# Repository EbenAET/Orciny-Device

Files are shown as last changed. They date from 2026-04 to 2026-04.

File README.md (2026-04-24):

# Orciny Device Unified Firmware (V 1.0.0) ~ Show Release

## Overview

This repository contains the complete, unified firmware and documentation for the Orciny Device: a single-controller, multi-effect system built around the Adafruit Feather RP2040. All device logic, state management, and effect sequencing are implemented in a single, modular program with robust configuration and documentation.

## Backstage Instructions

- **Setup:**
	- Check that 5V battery is plugged in to device USB cable
		- Located in broken end of device
		- Be sure 5V charging cable is unplugged and detatched from device
	- Tuck Programming/Charging cable into center and secure end
		- Located between "Core" and "Rotary" setions
		- Gently feed excess cable into cavity until only painted portion remains
		- Stick velcro end of cable to receiving pad
	- Test Device
		- Press "power" button to enable outputs
			- Back end should start slowly sparking
		- Press "play/pause" button to start sequence
			- Core animation should start (slowly at first, then ramping up)
		- If full program runs, its ready to go! Set for show!
	- Handoff
		- When in standby to hand off, check that device is still in "inactive/idle" by pressing "power" button
		- If in the correct state, there should be intermittent sparks and no other animations
		- If other animations start up, let the program run through or press the "Break" button to fastforward to the device failure sequence, after which the device will return to "Idle" sequence with outputs off
			- At this point, press the "power" button to make sure outputs are on and device is in "Inactive/Idle"
- **Charging:**
	- Device has two batteries for operation
		- 5V power bank in tail
		- 3.7V LiPO internally
	- 5V battery should only need charging every couple of performances if device USB is unplugged when not in use
		- Charges with MicroUSB cable as needed
	- 3.7V battery should be charged before each performance since we can't easily check status and we can't easily disconnect it
		- Charges with programming/charging cable tucked into midsection of device
		
### Physical Controls

- SW1 (`GP27`): Toggle outputs on/off
- SW2 (`GP28`): Play/Pause
- SW3 (`GP29`): Jump to Failure
- Hold SW1 + SW3 for 5 seconds: Reset to State 1 with outputs off

## Troubleshooting

- **Check troubleshooting document**
- **Additional assistance**
	- Contact Emery Smith or Eben Alguire
	
## Architecture

- **Main Program:**
	- `arduino/Orciny_Device/Orciny_Device.ino` — The only sketch you need. Implements the full state machine, effect sequencing, physical controls, and safety logic.
- **Configuration:**
	- `arduino/Orciny_Device/DeviceConfig.h` — All pin assignments and tunable parameters in one place.
- **Animation & Palette Data:**
	- `arduino/Orciny_Device/ColorPalettes.h`, `arduino/Orciny_Device/AnimationPalettes.h` — All color, timing, and animation data.
- **Shared Logic:**
	- `arduino/libraries/OrcinyCommon` — Protocols, data structures, and shared code.
- **Optional Advanced Scenes:**
	- `arduino/libraries/OrcinyEffects` — Pre-built effect scenes for advanced/hybrid workflows (not required for standard operation).
- **Documentation:**
	- Markdown files in `arduino/Orciny_Device/` detail the animation timeline, troubleshooting, and visualizations.

## Project Structure

- `arduino/Orciny_Device/Orciny_Device.ino` — Main program
- `arduino/Orciny_Device/DeviceConfig.h` — Pin/parameter config
- `arduino/Orciny_Device/Orciny_Device_Animation_Timeline.md` — Detailed animation timeline
- `arduino/Orciny_Device/Orciny_Device_Animation_Timeline_Visual.md` — Visual timeline (ASCII/Mermaid)
- `arduino/Orciny_Device/Orciny_Device_Troubleshooting.md` — Troubleshooting guide
- `arduino/libraries/OrcinyCommon` — Shared code
- `arduino/libraries/OrcinyEffects` — Optional advanced scenes
- `arduino/rp2040_fx_starter` — Minimal starter sketch (for bring-up only)
- `arduino/depreciated/` — Legacy/old sketches

## How to Program

1. **Set Up Arduino IDE:**
	 - Set your Sketchbook location to the repo’s `arduino` folder.
	 - Install required libraries: Adafruit NeoPixel, Adafruit PWM Servo Driver Library.
2. **Open the Main Sketch:**
	 - Open `arduino/Orciny_Device/Orciny_Device.ino`.
	 - Select the Feather RP2040 board.
3. **Configure Hardware:**
	 - Edit `DeviceConfig.h` for your pinout and hardware specifics.
4. **Upload and Test:**
	 - Upload to your device and test with the physical switches.
5. **Reference Documentation:**
	 - See the Markdown docs for animation timing, troubleshooting, and wiring.
	 
## Documentation

- [Animation Timeline](arduino/Orciny_Device/Orciny_Device_Animation_Timeline.md): State-by-state effect breakdown
- [Troubleshooting](arduino/Orciny_Device/Orciny_Device_Troubleshooting.md): Physical device troubleshooting

## Versioning & Stability

- **Current Version:** V 0.9.0
- All configuration, palette, and animation headers are centralized.
- State-tracking and reset logic are robust and up-to-date.
- Use this version as your restore point for stable builds.

## Hardware & Wiring Notes

- All pin/parameter definitions: `DeviceConfig.h`
- Color/animation minutiae: `ColorPalettes.h`, `AnimationPalettes.h`
- Power, wiring, and hardware are detailed in the troubleshooting and timeline docs.
- This firmware is a framework: PWM levels, animation timing, and thermal limits require bench validation for new or modified builds.

---

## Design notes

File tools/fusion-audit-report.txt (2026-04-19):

MODE=Audit
MCP_URL=http://127.0.0.1:27182/mcp
REPO_PATH=C:\Users\ebena\OneDrive - University of Illinois - Urbana\Documents\GitHub\Orciny-Device
EXPORT_ROOT=C:\Users\ebena\OneDrive - University of Illinois - Urbana\Documents\GitHub\Orciny-Device\3d Models\Archive\fusion_auto
PROJECT_FILTER=
NAMELIKE_FILTER=
FORMAT_FILTER=f3d,step
PROJECT_MAP_PATH=C:\Users\ebena\OneDrive - University of Illinois - Urbana\Documents\GitHub\Orciny-Device\tools\fusion-project-map.json
PROJECT_MAP_ACTIVE=True
MATCH_COUNT=37
MATCH=0000 Device Assembly | urn:adsk.wipprod:dm.lineage:0i7we0qBRXyN4Au_lZAOfA | City and the City - Orciny Device | City and the City - Orciny Device | subfolder=orciny-device | formats=f3d,step,stl
MATCH=Donuts | urn:adsk.wipprod:dm.lineage:x_f3pI8QSxqb1imuMA4Tkw | City and the City - Orciny Device | City and the City - Orciny Device | subfolder=orciny-device | formats=f3d,step,stl
MATCH=Large disk insert | urn:adsk.wipprod:dm.lineage:e5Ka2zAoSriwOnS_mKsbtw | City and the City - Orciny Device | City and the City - Orciny Device | subfolder=orciny-device | formats=f3d,step,stl
MATCH=Pincer2 | urn:adsk.wipprod:dm.lineage:Z4H9nMHJRkywdjsSsq7myw | City and the City - Orciny Device | City and the City - Orciny Device | subfolder=orciny-device | formats=f3d,step,stl
MATCH=adafruit | urn:adsk.wipprod:dm.lineage:Ej6vKYrnSt-ZIFgxbDMd9g | City and the City - Orciny Device | Circuit | subfolder=orciny-device | formats=f3d,step,stl
MATCH=Pin | urn:adsk.wipprod:dm.lineage:PLMYrBxTQdqTRPHx7Qjl8w | City and the City - Orciny Device | City and the City - Orciny Device | subfolder=orciny-device | formats=f3d,step,stl
MATCH=End connector | urn:adsk.wipprod:dm.lineage:xL0HUBYZQrGGkRIrOdHDPw | City and the City - Orciny Device | City and the City - Orciny Device | subfolder=orciny-device | formats=f3d,step,stl
MATCH=Nozzle | urn:adsk.wipprod:dm.lineage:XH76Vv6oStSqThVJ8LdOsw | City and the City - Orciny Device | City and the City - Orciny Device | subfolder=orciny-device | formats=f3d,step,stl
MATCH=Rotary Shaft | urn:adsk.wipprod:dm.lineage:Y_C4eCmAQlGzDhUTAhTmWw | City and the City - Orciny Device | City and the City - Orciny Device | subfolder=orciny-device | formats=f3d,step,stl
MATCH=Coupler | urn:adsk.wipprod:dm.lineage:pr6ihEBnSuqMdRxkfSCbQw | City and the City - Orciny Device | City and the City - Orciny Device | subfolder=orciny-device | formats=f3d,step,stl
MATCH=Central shaft | urn:adsk.wipprod:dm.lineage:qKA4xiB4RSe2X-p6imrm5g | City and the City - Orciny Device | City and the City - Orciny Device | subfolder=orciny-device | formats=f3d,step,stl
MATCH=Broken tail | urn:adsk.wipprod:dm.lineage:KY0QbmYLRIuuyMJGiDZOdw | City and the City - Orciny Device | City and the City - Orciny Device | subfolder=orciny-device | formats=f3d,step,stl
MATCH=Mounting Martrix | urn:adsk.wipprod:dm.lineage:OBUW4VHMSKGCA77YboDdjg | City and the City - Orciny Device | City and the City - Orciny Device | subfolder=orciny-device | formats=f3d,step,stl
MATCH=emeey pinchers pt1 | urn:adsk.wipprod:dm.lineage:gWEqI1OyTM-vEEHmxptcwQ | City and the City - Orciny Device | Archive | subfolder=orciny-device | formats=f3d,step,stl
MATCH=Pincer Mesh | urn:adsk.wipprod:dm.lineage:DkKWn12oQ7KZ3K4VdfnyJQ | City and the City - Orciny Device | Archive | subfolder=orciny-device | formats=f3d,step,stl
MATCH=Clay pincer meshmodel | urn:adsk.wipprod:dm.lineage:GIoec0_ZQzCYo7EZ0XneOQ | City and the City - Orciny Device | Mesh scans | subfolder=orciny-device | formats=f3d,step,stl
MATCH=Device Nozzle | urn:adsk.wipprod:dm.lineage:wPSjv7ReQXulWAZpgUlfvQ | City and the City - Orciny Device | Archive | subfolder=orciny-device | formats=f3d,step,stl
MATCH=Pincer | urn:adsk.wipprod:dm.lineage:LqhbNozhQHq2CwXfs8nBlQ | City and the City - Orciny Device | Archive | subfolder=orciny-device | formats=f3d,step,stl
MATCH=emery test | urn:adsk.wipprod:dm.lineage:FYrKI2XZQSa07a1-etMyPg | City and the City - Orciny Device | Archive | subfolder=orciny-device | formats=f3d,step,stl
MATCH=Emery Test | urn:adsk.wipprod:dm.lineage:BRCgBeIaSra0wubaWRF43Q | City and the City - Orciny Device | Archive | subfolder=orciny-device | formats=f3d,step,stl
MATCH=emery test | urn:adsk.wipprod:dm.lineage:FaK44H6cSXKmsoEH3gZrqg | City and the City - Orciny Device | Archive | subfolder=orciny-device | formats=f3d,step,stl
MATCH=Nozzle Cap | urn:adsk.wipprod:dm.lineage:_48LmerfRO-RmRAW0qVxWA | City and the City - Orciny Device | Archive | subfolder=orciny-device | formats=f3d,step,stl
MATCH=000 Claw assembly | urn:adsk.wipprod:dm.lineage:s7H_Vr9sT2ukSLe7j24oaw | Orciny device | Orciny device | subfolder=orciny-device-next | formats=f3d,step,stl
MATCH=Screw | urn:adsk.wipprod:dm.lineage:RjQVy1nPQRKoVIJjv0cjCQ | Orciny device | Orciny device | subfolder=orciny-device-next | formats=f3d,step,stl
MATCH=0000 Effect Assembly | urn:adsk.wipprod:dm.lineage:MgjUV8lTTwCATlut9x-gGg | Radium Girls | Radium Girls | subfolder=radium-girls | formats=f3d,step
MATCH=Bung | urn:adsk.wipprod:dm.lineage:AIxvFMD1TlaubFQTPOqOWw | Radium Girls | Radium Girls | subfolder=radium-girls | formats=f3d,step
MATCH=PCB3 | urn:adsk.wipprod:dm.lineage:rGX81_E_SMe7DuCYjnw8zg | Radium Girls | Radium Girls | subfolder=radium-girls | formats=f3d,step
MATCH=PCB3 | urn:adsk.wipprod:dm.lineage:CceROSsmQnKhIDO-hsE-gQ | Radium Girls | Radium Girls | subfolder=radium-girls | formats=f3d,step
MATCH=PCB3 | urn:adsk.wipprod:dm.lineage:Wt0j8bskTZ-lOoiLNmkJyQ | Radium Girls | Radium Girls | subfolder=radium-girls | formats=f3d,step
MATCH=PCB Assembly | urn:adsk.wipprod:dm.lineage:iWvl_ixJS6KupJv7bIMY4w | Radium Girls | Radium Girls | subfolder=radium-girls | formats=f3d,step
MATCH=PCB3 | urn:adsk.wipprod:dm.lineage:zwZO-YlHRzK7X6FbYi3zog | Radium Girls | Radium Girls | subfolder=radium-girls | formats=f3d,step
MATCH=4 pin fpc | urn:adsk.wipprod:dm.lineage:DiI6vidnQ76GTtji4kISsQ | Radium Girls | Radium Girls | subfolder=radium-girls | formats=f3d,step
MATCH=2026-02-20_17-37-38_Library | urn:adsk.wipprod:dm.lineage:nSYjRbDsSKOJwaZLO-sgmA | Radium Girls | Radium Girls | subfolder=radium-girls | formats=f3d,step
MATCH=CONN4_93-0470_MOL | urn:adsk.wipprod:dm.lineage:B5IE1y8fR1q9EawdSpntRA | Radium Girls | Radium Girls | subfolder=radium-girls | formats=f3d,step
MATCH=4pin FPC Connector | urn:adsk.wipprod:dm.lineage:t7W2Dlk1TRiYh1G_xvv78A | Radium Girls | Radium Girls | subfolder=radium-girls | formats=f3d,step
MATCH=Connectorcust | urn:adsk.wipprod:dm.lineage:igUmLseoQQ6BJsJLfTLd6g | Radium Girls | Radium Girls | subfolder=radium-girls | formats=f3d,step
MATCH=PCB2 | urn:adsk.wipprod:dm.lineage:SoFJXjL8RjyrG6MS-hq-GQ | Radium Girls | Radium Girls | subfolder=radium-girls | formats=f3d,step

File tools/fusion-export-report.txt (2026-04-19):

MODE=Export
MCP_URL=http://127.0.0.1:27182/mcp
REPO_PATH=C:\Users\ebena\OneDrive - University of Illinois - Urbana\Documents\GitHub\Orciny-Device
EXPORT_ROOT=C:\Users\ebena\OneDrive - University of Illinois - Urbana\Documents\GitHub\Orciny-Device\3d Models\Archive\fusion_auto
PROJECT_FILTER=
NAMELIKE_FILTER=
FORMAT_FILTER=f3d,step
PROJECT_MAP_PATH=C:\Users\ebena\OneDrive - University of Illinois - Urbana\Documents\GitHub\Orciny-Device\tools\fusion-project-map.json
PROJECT_MAP_ACTIVE=True
MATCH_COUNT=37
MATCH=0000 Device Assembly | urn:adsk.wipprod:dm.lineage:0i7we0qBRXyN4Au_lZAOfA | City and the City - Orciny Device | City and the City - Orciny Device | subfolder=orciny-device | formats=f3d,step,stl
MATCH=Donuts | urn:adsk.wipprod:dm.lineage:x_f3pI8QSxqb1imuMA4Tkw | City and the City - Orciny Device | City and the City - Orciny Device | subfolder=orciny-device | formats=f3d,step,stl
MATCH=Large disk insert | urn:adsk.wipprod:dm.lineage:e5Ka2zAoSriwOnS_mKsbtw | City and the City - Orciny Device | City and the City - Orciny Device | subfolder=orciny-device | formats=f3d,step,stl
MATCH=Pincer2 | urn:adsk.wipprod:dm.lineage:Z4H9nMHJRkywdjsSsq7myw | City and the City - Orciny Device | City and the City - Orciny Device | subfolder=orciny-device | formats=f3d,step,stl
MATCH=adafruit | urn:adsk.wipprod:dm.lineage:Ej6vKYrnSt-ZIFgxbDMd9g | City and the City - Orciny Device | Circuit | subfolder=orciny-device | formats=f3d,step,stl
MATCH=Pin | urn:adsk.wipprod:dm.lineage:PLMYrBxTQdqTRPHx7Qjl8w | City and the City - Orciny Device | City and the City - Orciny Device | subfolder=orciny-device | formats=f3d,step,stl
MATCH=End connector | urn:adsk.wipprod:dm.lineage:xL0HUBYZQrGGkRIrOdHDPw | City and the City - Orciny Device | City and the City - Orciny Device | subfolder=orciny-device | formats=f3d,step,stl
MATCH=Nozzle | urn:adsk.wipprod:dm.lineage:XH76Vv6oStSqThVJ8LdOsw | City and the City - Orciny Device | City and the City - Orciny Device | subfolder=orciny-device | formats=f3d,step,stl
MATCH=Rotary Shaft | urn:adsk.wipprod:dm.lineage:Y_C4eCmAQlGzDhUTAhTmWw | City and the City - Orciny Device | City and the City - Orciny Device | subfolder=orciny-device | formats=f3d,step,stl
MATCH=Coupler | urn:adsk.wipprod:dm.lineage:pr6ihEBnSuqMdRxkfSCbQw | City and the City - Orciny Device | City and the City - Orciny Device | subfolder=orciny-device | formats=f3d,step,stl
MATCH=Central shaft | urn:adsk.wipprod:dm.lineage:qKA4xiB4RSe2X-p6imrm5g | City and the City - Orciny Device | City and the City - Orciny Device | subfolder=orciny-device | formats=f3d,step,stl
MATCH=Broken tail | urn:adsk.wipprod:dm.lineage:KY0QbmYLRIuuyMJGiDZOdw | City and the City - Orciny Device | City and the City - Orciny Device | subfolder=orciny-device | formats=f3d,step,stl
MATCH=Mounting Martrix | urn:adsk.wipprod:dm.lineage:OBUW4VHMSKGCA77YboDdjg | City and the City - Orciny Device | City and the City - Orciny Device | subfolder=orciny-device | formats=f3d,step,stl
MATCH=emeey pinchers pt1 | urn:adsk.wipprod:dm.lineage:gWEqI1OyTM-vEEHmxptcwQ | City and the City - Orciny Device | Archive | subfolder=orciny-device | formats=f3d,step,stl
MATCH=Pincer Mesh | urn:adsk.wipprod:dm.lineage:DkKWn12oQ7KZ3K4VdfnyJQ | City and the City - Orciny Device | Archive | subfolder=orciny-device | formats=f3d,step,stl
MATCH=Clay pincer meshmodel | urn:adsk.wipprod:dm.lineage:GIoec0_ZQzCYo7EZ0XneOQ | City and the City - Orciny Device | Mesh scans | subfolder=orciny-device | formats=f3d,step,stl
MATCH=Device Nozzle | urn:adsk.wipprod:dm.lineage:wPSjv7ReQXulWAZpgUlfvQ | City and the City - Orciny Device | Archive | subfolder=orciny-device | formats=f3d,step,stl
MATCH=Pincer | urn:adsk.wipprod:dm.lineage:LqhbNozhQHq2CwXfs8nBlQ | City and the City - Orciny Device | Archive | subfolder=orciny-device | formats=f3d,step,stl
MATCH=emery test | urn:adsk.wipprod:dm.lineage:FYrKI2XZQSa07a1-etMyPg | City and the City - Orciny Device | Archive | subfolder=orciny-device | formats=f3d,step,stl
MATCH=Emery Test | urn:adsk.wipprod:dm.lineage:BRCgBeIaSra0wubaWRF43Q | City and the City - Orciny Device | Archive | subfolder=orciny-device | formats=f3d,step,stl
MATCH=emery test | urn:adsk.wipprod:dm.lineage:FaK44H6cSXKmsoEH3gZrqg | City and the City - Orciny Device | Archive | subfolder=orciny-device | formats=f3d,step,stl
MATCH=Nozzle Cap | urn:adsk.wipprod:dm.lineage:_48LmerfRO-RmRAW0qVxWA | City and the City - Orciny Device | Archive | subfolder=orciny-device | formats=f3d,step,stl
MATCH=000 Claw assembly | urn:adsk.wipprod:dm.lineage:s7H_Vr9sT2ukSLe7j24oaw | Orciny device | Orciny device | subfolder=orciny-device-next | formats=f3d,step,stl
MATCH=Screw | urn:adsk.wipprod:dm.lineage:RjQVy1nPQRKoVIJjv0cjCQ | Orciny device | Orciny device | subfolder=orciny-device-next | formats=f3d,step,stl
MATCH=0000 Effect Assembly | urn:adsk.wipprod:dm.lineage:MgjUV8lTTwCATlut9x-gGg | Radium Girls | Radium Girls | subfolder=radium-girls | formats=f3d,step
MATCH=Bung | urn:adsk.wipprod:dm.lineage:AIxvFMD1TlaubFQTPOqOWw | Radium Girls | Radium Girls | subfolder=radium-girls | formats=f3d,step
MATCH=PCB3 | urn:adsk.wipprod:dm.lineage:rGX81_E_SMe7DuCYjnw8zg | Radium Girls | Radium Girls | subfolder=radium-girls | formats=f3d,step
MATCH=PCB3 | urn:adsk.wipprod:dm.lineage:CceROSsmQnKhIDO-hsE-gQ | Radium Girls | Radium Girls | subfolder=radium-girls | formats=f3d,step
MATCH=PCB3 | urn:adsk.wipprod:dm.lineage:Wt0j8bskTZ-lOoiLNmkJyQ | Radium Girls | Radium Girls | subfolder=radium-girls | formats=f3d,step
MATCH=PCB Assembly | urn:adsk.wipprod:dm.lineage:iWvl_ixJS6KupJv7bIMY4w | Radium Girls | Radium Girls | subfolder=radium-girls | formats=f3d,step
MATCH=PCB3 | urn:adsk.wipprod:dm.lineage:zwZO-YlHRzK7X6FbYi3zog | Radium Girls | Radium Girls | subfolder=radium-girls | formats=f3d,step
MATCH=4 pin fpc | urn:adsk.wipprod:dm.lineage:DiI6vidnQ76GTtji4kISsQ | Radium Girls | Radium Girls | subfolder=radium-girls | formats=f3d,step
MATCH=2026-02-20_17-37-38_Library | urn:adsk.wipprod:dm.lineage:nSYjRbDsSKOJwaZLO-sgmA | Radium Girls | Radium Girls | subfolder=radium-girls | formats=f3d,step
MATCH=CONN4_93-0470_MOL | urn:adsk.wipprod:dm.lineage:B5IE1y8fR1q9EawdSpntRA | Radium Girls | Radium Girls | subfolder=radium-girls | formats=f3d,step
MATCH=4pin FPC Connector | urn:adsk.wipprod:dm.lineage:t7W2Dlk1TRiYh1G_xvv78A | Radium Girls | Radium Girls | subfolder=radium-girls | formats=f3d,step
MATCH=Connectorcust | urn:adsk.wipprod:dm.lineage:igUmLseoQQ6BJsJLfTLd6g | Radium Girls | Radium Girls | subfolder=radium-girls | formats=f3d,step
MATCH=PCB2 | urn:adsk.wipprod:dm.lineage:SoFJXjL8RjyrG6MS-hq-GQ | Radium Girls | Radium Girls | subfolder=radium-girls | formats=f3d,step
EXPORTED_COUNT=37
FAILED_COUNT=0
EXPORTED=0000 Device Assembly -> orciny-device
EXPORTED=Donuts -> orciny-device
EXPORTED=Large disk insert -> orciny-device
EXPORTED=Pincer2 -> orciny-device
EXPORTED=adafruit -> orciny-device
EXPORTED=Pin -> orciny-device
EXPORTED=End connector -> orciny-device
EXPORTED=Nozzle -> orciny-device
EXPORTED=Rotary Shaft -> orciny-device
EXPORTED=Coupler -> orciny-device
EXPORTED=Central shaft -> orciny-device
EXPORTED=Broken tail -> orciny-device
EXPORTED=Mounting Martrix -> orciny-device
EXPORTED=emeey pinchers pt1 -> orciny-device
EXPORTED=Pincer Mesh -> orciny-device
EXPORTED=Clay pincer meshmodel -> orciny-device
EXPORTED=Device Nozzle -> orciny-device
EXPORTED=Pincer -> orciny-device
EXPORTED=emery test -> orciny-device
EXPORTED=Emery Test -> orciny-device
EXPORTED=emery test -> orciny-device
EXPORTED=Nozzle Cap -> orciny-device
EXPORTED=000 Claw assembly -> orciny-device-next
EXPORTED=Screw -> orciny-device-next
EXPORTED=0000 Effect Assembly -> radium-girls
EXPORTED=Bung -> radium-girls
EXPORTED=PCB3 -> radium-girls
EXPORTED=PCB3 -> radium-girls
EXPORTED=PCB3 -> radium-girls
EXPORTED=PCB Assembly -> radium-girls
EXPORTED=PCB3 -> radium-girls
EXPORTED=4 pin fpc -> radium-girls
EXPORTED=2026-02-20_17-37-38_Library -> radium-girls
EXPORTED=CONN4_93-0470_MOL -> radium-girls
EXPORTED=4pin FPC Connector -> radium-girls
EXPORTED=Connectorcust -> radium-girls
EXPORTED=PCB2 -> radium-girls

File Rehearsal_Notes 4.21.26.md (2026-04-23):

<!-- Device Rehearsal Notes | V 1.0.0 (Show Release) | Updated: 2026-04-21 -->

# Device Rehearsal Notes

## General Information
- **Date:**
    - April 21, 2026
- **Device/Module:**
    - Orciny Device Production version
- **Tested by:**
    - Eben Alguire, Emery Smith, Chris Ramshaw *Bowden*
- **Purpose/Focus:**
    - Dress Rehearsal 1, Tech

---

## Hardware Notes
- **Observed Issues:**
	- Hard to tell what state its in during early boot mode, but that might be okay
    - Buttons too sensative
    - Pulse filament seems to be linked directly to pump, no fading just on or off when the pump is on or off
        - Work on fix if there is time, but not a priority
- **Physical Adjustments/Repairs:**
	- More rust, more goop
- **Component Status:**
	- Intact, learning

---

## Programming Notes
- **Firmware/Code Version:**
    - 0.7.0
- **Observed Bugs/Glitches:**
	- 
- **Feature Requests/Ideas:**
	-
- **Upload/Debug Actions:**
	-

---

## Miscellaneous
- **Other Observations:**
	- Performer is geting used to the states and button placement
- **Questions/Follow-ups:**
	- Do we need to increase debounce to avoid accidental button presses?
- **To do:**
    - Provide digital and paper copies of the troubleshooting guide, charging and maintenance, etc
    - Package design, instruct backstage and Emery on how to upload, debug, etc
---

*Version: V 1.0.0 (Show Release)*

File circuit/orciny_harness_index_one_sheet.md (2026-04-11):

# Orciny Harness Index (One Sheet)

Quick-reference index for harness identification during build and troubleshooting.

| Label | Harness ID | Primary Connector | From | To | Notes |
|---|---|---|---|---|---|
| 1 | H-PWR-5V | Header / terminal (project-defined) | J801 / +5V input | +5V_BUS branches | 18 AWG trunk, 20 AWG branches |
| 2 | H-BAT-NEO | 2-pin JST | LP503562 #2 + U812 output | +3V7_NEO rail | red=+, black=-; 500-1000 uF bulk cap at strip entry |
| 3 | H-CORE | 3-pin JST HX (NeoPixel side); splits from same 4-pin cable as H-BAT-NEO | RP2040 GP25, +5V_BUS, GND_COMMON | NeoPixel strip DI, +V, GND | Pin 1 red=+V, pin 2 white=signal, pin 3 black+brown=GND; cap across pins 1-3 |
| 4 | H-SW | 4-pin JST | SW1/SW2/SW3, GND | RP2040 A1/A2/A3 (GP27/GP28/GP29), GND | Pin 1 blue=SW1, pin 2 brown=SW2, pin 3 orange=SW3, pin 4 green=GND |
| 5 | H-SPARK | 5-pin DMX cable | RP2040 GP18/GP19/GP20/GP24, GND | Spark channels 1-4 (+ spare) | green=GND; pin 1 red=SP1, pin 2 brown=SP2, pin 3 white=SP3, pin 4 blue=SP4, pin 5 black=spare |
| 6 | H-SERVO | 4-pin JST | ServoWing outputs/power | Servo A/B signal + power branches | Pin 1 white=CH0 sig, pin 2 blue=CH1 sig, pin 3 red=PWR, pin 4 black=GND |
| 7 | H-BEAM-PWR | 4-pin JST (common anode RGB LED) | +5V_BUS, GND_COMMON | Beam load path | Pin 1 white=anode, pin 2 red=R(GP11), pin 3 blue=B(GP13), pin 4 green=G(GP12); GP10 reserved for Prop-Maker PWR enable |
| 8 | H-PELTIER-PWR | Deans Micro2R | +5V_BUS, GND_COMMON | Peltier load path | Pin 1 red=PWR, pin 2 black=GND; GP8->Q9 gate; firmware ON with beam + short cooldown hold |
| 9 | H-PUMP-OPT | Project-defined load/control connector | GPIO unassigned (this revision), +5V_BUS, GND_COMMON | Optional pump driver + load branch | GP8 reassigned to peltier; optional population |
| 10 | H-BAT-RP | Feather battery JST | LP503562 #1 | Feather RP2040 BAT/GND | Direct battery harness; Feather onboard charger path |

## Rail Separation Reminder

- Keep +5V_BUS, RP2040_BAT, and +3V7_NEO isolated from each other.
- Only tie grounds at GND_COMMON.
- Neo battery charger U812 remains dedicated to the Neo rail battery only.

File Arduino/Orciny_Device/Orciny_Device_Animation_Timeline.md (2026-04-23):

# Orciny Device Animation Timeline

**Version:** V 0.9.0  
**Board:** Adafruit Feather RP2040  
**Wings:** Prop-Maker FeatherWing, 8-Channel Servo FeatherWing (PCA9685)

---

## Animation Sequence Timeline
- **Program runtime:** Approximately 47 seconds from start of Boot Up to end of Device Failure
	- Performer is able to pause the sequence to slow it down or jump to Device Failure if it needs to finish faster

### State 0: INACTIVE (Sequence 0)
- **0s+**: Sparse random single sparks every 3–5 seconds
- **Beam & NeoPixels:** Off

---

### State 1: BOOT UP (Sequence 1)
- **0–4s**: Sparse sparks; cyan chases (slow to fast)
- **4–14s**: Sparks continue; cyan chases ramp up
- **14–22s**: Orange chases begin; pincers go rigid
- **22–24s**: Core pulses cyan/orange; beam fades to golden
- **24–26s**: Servo 1 oscillates
- **26–32s**: Both servos limp
- **32s+**: Transition to Demonstrate state

---

### State 2: DEMONSTRATE (Sequence 2)
- **0s**: Core flashes cyan/orange; beam brightens to orange (90%)
- **0.5s**: Beam fades to teal; both servos rigid
- **1s**: Fluid pump and pulse filament start turning on and off at random intervals
- **1.5s**: Servos random movement (slow, then frantic)
- **2s**: Sparks start; magenta chases on core
- **3–7s**: Beam pulses teal/orange with accelerating frequency
- **7s**: Core all-off; beam turns magenta (30%)
- **7.25s**: Beam magenta fades to full; pincers freeze
- **9.5s**: Pincers freeze up
- **10.75s**: Transition to Device Failure state

---

### State 3: DEVICE FAILURE (Sequence 3)
- **0s**: Random twitching servos; sparks increase in frequency; core rapid flashes all colors
- **0–4s**: Beam flashes teal/magenta/orange
- **1.75s**: Core → bright white
- **2s**: Core fades out; beam all colors full
- **2.5s**: Beam fades out; pincers go limp
- **3s**: Fluid pump seizes, pulse filament to full
- **3.5s**: Pincers go limp
- **4s+**: Everything off, output disabled

---

## Notes
- **Physical Controls:**
  - SW1: Toggle all outputs on/off
  - SW2: Play/Pause
  - SW3: Jump to Device Failure
  - SW1 + SW3 held 5s: Reset to State 1, outputs off
- **See** `Orciny_Device.ino` for detailed implementation.

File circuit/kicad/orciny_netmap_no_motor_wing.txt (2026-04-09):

ORCINY KICAD NET MAP - RP2040 ONLY
==================================
Current electrical reference for the RP2040-only hardware build.

Controller and UI
- RP2040 is the only controller in this revision.
- SW1: RP2040_A1 (GP27) -> switch -> GND (toggle output on/off)
- SW2: RP2040_A2 (GP28) -> switch -> GND (previous sequence)
- SW3: RP2040_A3 (GP29) -> switch -> GND (next sequence)
- Hold SW1+SW3 for 5 seconds -> reset to sequence 1

NeoPixel core
- RP2040_GP4 -> NeoPixel_Data (Adafruit 4865, SK6812, 166 pixels)
- +3V7_NEO -> NeoPixel_Power
- GND_COMMON -> NeoPixel_Ground

RP2040 effect outputs
- RP2040_GP7  -> R601 -> SPARK1_FILAMENT
- RP2040_GP6  -> R602 -> SPARK2_FILAMENT
- RP2040_GP9  -> R603 -> SPARK3_FILAMENT
- RP2040_GP24 -> R604 -> SPARK4_FILAMENT
- RP2040_GP10 -> PROPMAKER_PWR_ENABLE (held HIGH)
- RP2040_GP11 -> PROPMAKER_LED1_CTRL
- RP2040_GP12 -> PROPMAKER_LED2_CTRL
- RP2040_GP13 -> PROPMAKER_LED3_CTRL
- RP2040_GP8 -> PELTIER_ENABLE_GATE (Q9)
- RP2040_I2C_SDA -> SERVO_WING_SDA
- RP2040_I2C_SCL -> SERVO_WING_SCL
- SERVO_WING_CH0 -> SERVO_A_SIGNAL
- SERVO_WING_CH1 -> SERVO_B_SIGNAL
- PUMP_ENABLE_GATE_OPTIONAL -> GPIO unassigned in this revision (optional, firmware disabled)

Power domains
- +5V_IN (from 5V battery via main fuse)
  +-> F801
  +-> +5V_BUS (ServoWing + Prop-Maker/peltier + optional pump)

- RP2040_BAT_IN (from dedicated LP503562 battery #1 at J811)
  +-> Feather RP2040 BAT input (Feather onboard charger path)
  +-> RP2040_BAT domain (controller and spark branch)

- +3V7_NEO_IN (from dedicated LP503562 battery #2 at J812)
  +-> +3V7_NEO (NeoPixel strip supply)

- CHG_NEO_USB_5V -> U812 (Adafruit 259) -> LP503562 battery #2 (J812)

Load domain summary
- +5V_BUS -> Servo FeatherWing, Prop-Maker LED stage, peltier source, optional pump
- RP2040_BAT -> RP2040 logic and direct spark filament branch
- +3V7_NEO -> NeoPixel strip only

Spark branch
- Spark channels are direct RP2040 GPIO outputs through 10 ohm series resistors.
- R601-R604: one 10 ohm resistor per spark channel.

Prop-Maker and servo domains
- Prop-Maker control inputs: GP11/GP12/GP13, with GP10 held HIGH for PWR enable
- Prop-Maker load supply domain: +5V_BUS
- Peltier control: GP8 drives Q9; firmware enables peltier while beam is active and holds peltier on briefly after beam off for heat dissipation
- ServoWing control: I2C SDA/SCL from RP2040
- ServoWing power: +5V_BUS and GND_COMMON

Optional pump branch
- Gate: GPIO unassigned in this revision (GP8 repurposed to peltier)
- Drain: load negative
- Source: GND_COMMON
- Load positive: +5V_BUS

Connector mapping
- J801: 5V power input connector (JST XT60 or barrel jack)
- J802: power distribution hub (+5V_BUS, RP2040_BAT, +3V7_NEO, GND)
- J811: RP2040 main battery input (LP503562 #1)
- J812: NeoPixel battery input (LP503562 #2)
- U812: Adafruit 259 charger for J812 NeoPixel battery only
- J601: spark PWM bus input (SPARK1-4 + GND from RP2040)
- J603: spark load outputs (post-resistor)
- J701: Prop-Maker control header (LED1/LED2/LED3 control + GND)
- J702: 3-9W LED output connector
- J703: peltier load output
- J401: optional pump output
- J402: Servo A connector (signal + +5V_BUS + GND)
- J403: Servo B connector (signal + +5V_BUS + GND)

Grounding rules
- [MANDATORY] Tie all grounds together:
  - RP2040 ground
  - LP503562 RP2040 battery negative
  - LP503562 NeoPixel battery negative
  - U812 charger ground
  - NeoPixel strip ground
  - Spark returns
  - Servo/Prop-Maker/pump/peltier returns
  - Switch grounds
  - 5V input negative

Rail isolation rules
- Keep +5V_BUS, RP2040_BAT, and +3V7_NEO positive rails isolated from each other.
- Keep U812 charger output isolated to the NeoPixel battery rail only.

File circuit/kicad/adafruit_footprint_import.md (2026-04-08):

# Adafruit Footprint Source Integration

This project now includes official Adafruit CAD repositories under this folder:

- `Adafruit-Eagle-Library` (official footprint/source library, includes `adafruit.lbr`)
- `Adafruit_CAD_Parts` (official product CAD archive; does not currently expose KiCad `.pretty` libs)

## What Was Configured

- Added project-local footprint table: `fp-lib-table`
- Registered library:
  - Name: `Adafruit_Eagle`
  - Type: `Eagle`
  - URI: `${KIPRJMOD}/Adafruit-Eagle-Library/adafruit.lbr`

## Using It In KiCad

1. Open the project in KiCad from this folder.
2. Open Symbol Editor / Schematic and assign footprints as needed.
3. In Footprint assignment, select the `Adafruit_Eagle` library.
4. Map each schematic component to the closest Adafruit package footprint.

## Concrete Assignments For This Project

- RP2040 Feather controller: `Adafruit_Eagle:FEATHERWING`
- SW1/SW2/SW3 momentary buttons: `Adafruit_Eagle:PUSHBUTTON_SMD_SJ`
- 5V DC input jack: `Adafruit_Eagle:DCJACK_2MM_PTH`
- Pump/Peltier 2-pin connector: `Adafruit_Eagle:JST-PH-2-THM`
- Beam terminal (4-pin): `Adafruit_Eagle:1X04-3.5MM`
- TO-220 MOSFET stages: `Adafruit_Eagle:TO220`

## Notes

- Adafruit's public `Adafruit-KiCad-Library` and `KiCad-Library` repositories are currently not available at those names.
- If Adafruit publishes/renames a native KiCad footprint repo later, update `fp-lib-table` to that `.pretty` path for a direct KiCad-native workflow.

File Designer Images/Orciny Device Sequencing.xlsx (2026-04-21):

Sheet: Sequence 0
Orciny Device Sequence
Sequence 0: "Inactive"
Output/Time (seconds) | 0 | 0.25 | 0.5 | 0.75 | 1 | 1.25 | 1.5 | 1.75 | 2 | 2.25 | 2.5 | 2.75 | 3 | 3.25 | 3.5 | 3.75 | 4 | 4.25 | 4.5 | 4.75 | 5 | 5.25 | 5.5 | 5.75 | 6 | 6.25 | 6.5 | 6.75 | 7 | 7.25 | 7.5 | 7.75 | 8 | 8.25 | 8.5 | 8.75 | 9 | 9.25 | 9.5 | 9.75 | 10 | 10.25 | 10.5
Sparks | Random single short flickers
Core
Beam
Pincer
Pump

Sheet: Sequence 1
Orciny Device Sequence
Sequence 1: "Boot up"
Output/Time (seconds) | 0 | 0.5 | 1 | 1.5 | 2 | 2.5 | 3 | 3.5 | 4 | 4.5 | 5 | 5.5 | 6 | 6.5 | 7 | 7.5 | 8 | 8.5 | 9 | 9.5 | 10 | 10.5 | 11 | 11.5 | 12 | 12.5 | 13 | 13.5 | 14 | 14.5 | 15 | 15.5 | 16 | 16.5 | 17 | 17.5 | 18 | 18.5 | 19 | 19.5 | 20 | 20.5 | 21 | 21.5 | 22 | 22.5 | 23 | 23.5 | 24
Sparks | Between 2-3 sparks randomly flash |  |  |  |  |  |  |  |  | Between 2-3 sparks randomly flash |  |  |  |  |  |  |  |  | Between 2-3 sparks randomly flash |  |  |  |  |  |  |  |  |  |  |  |  |  |  |  |  |  |  | Between 2-3 sparks randomly flash |  |  |  |  |  | Between 1-4 sparks randomly flash
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

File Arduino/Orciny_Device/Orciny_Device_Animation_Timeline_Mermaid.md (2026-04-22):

# Orciny Device Animation Timeline — Visual Table
Version: V 0.9.0

| Effect | 0–2 | 2–4 | 4–6 | 6–8 | 8–10 | 10–12 | 12–14 | 14–16 | 16–18 | 18–20 | 20–22 | 22–24 | 24–26 | 26–28 | 28–30 | 30–32 | 32–34 | 34–36 | 36–38 | 38–40 | 40–42 | 42–44 |
|---|-----|-----|-----|---|---|---|---|---|---|---|---|---|---|---|---|---|---|---|---|---|---|
| **Sparks** | | █ | █ | █ |  █ | █ | █ | █ | █ | █ | █ | █ | █ | █ | █ | █ | █ | █ | █ | | |
| **Core** | | █ | █ | █ |  █ | █ | █ | █ | █ | █ | █ | █ | █ | █ | █ | █ | █ | █ | █ | | |
| **Pincers** | | | | | | | | | | | | | | | █ | █ | █ | █ | █ | █ | |
| **Beam** | | | | | | | | | | | | | | | █ | █ | █ | █ | █ | | |
| **Pump** | | | | | | | | | | | | | | | | | | | █ | █ | █ |
||=============||=======||==========||=============||=============||=============||
| Inactive || Boot Up || Demonstration || Device Failure || || |

---

**Legend:**
- Each █ represents the effect being active during that time segment.
- Sequences are grouped by the leftmost column.
- For details, see the main Animation Timeline document.

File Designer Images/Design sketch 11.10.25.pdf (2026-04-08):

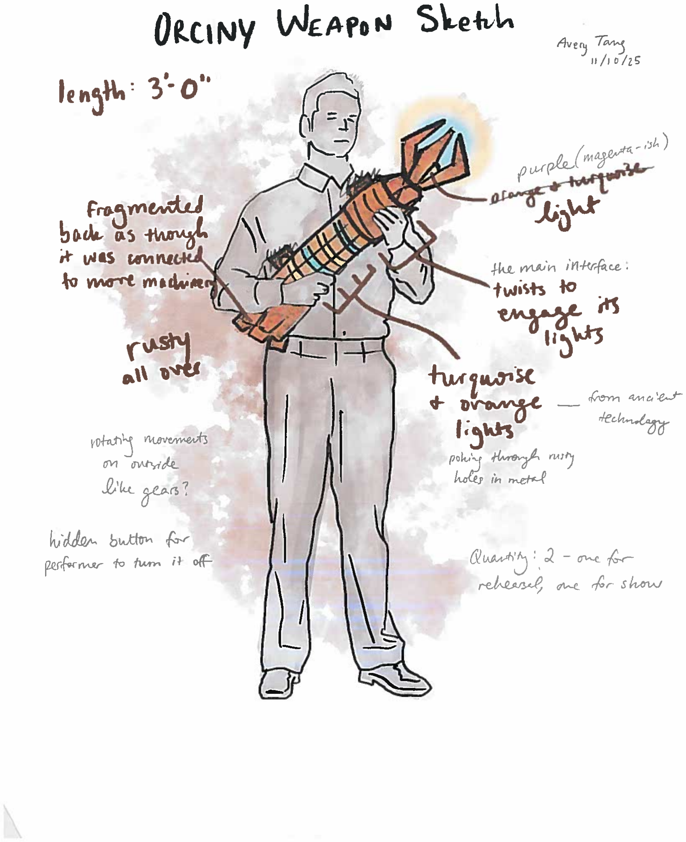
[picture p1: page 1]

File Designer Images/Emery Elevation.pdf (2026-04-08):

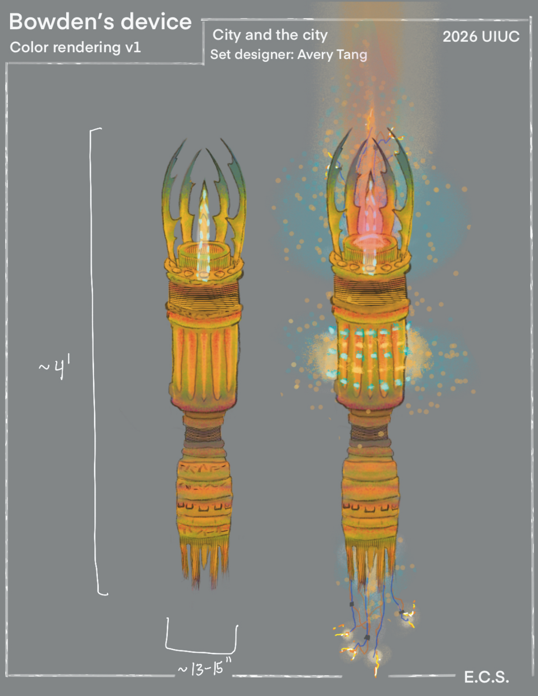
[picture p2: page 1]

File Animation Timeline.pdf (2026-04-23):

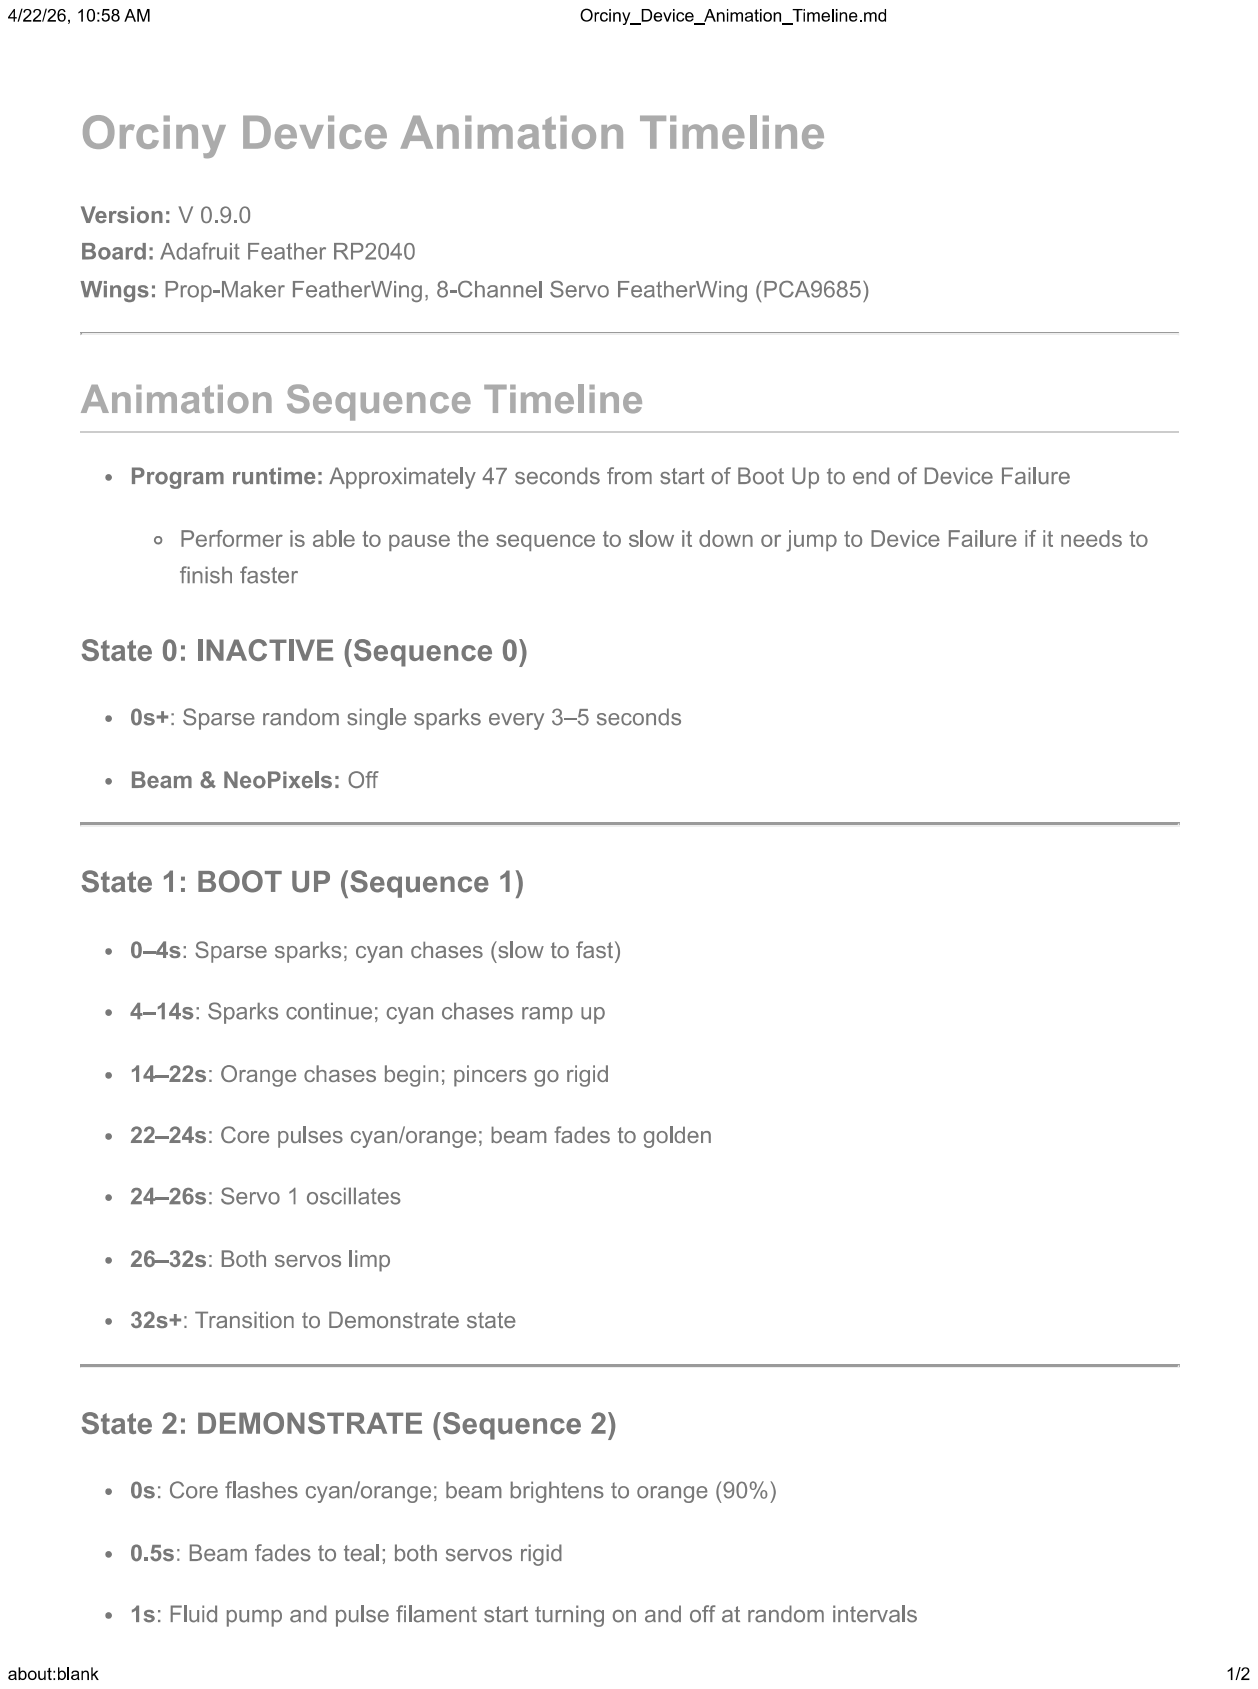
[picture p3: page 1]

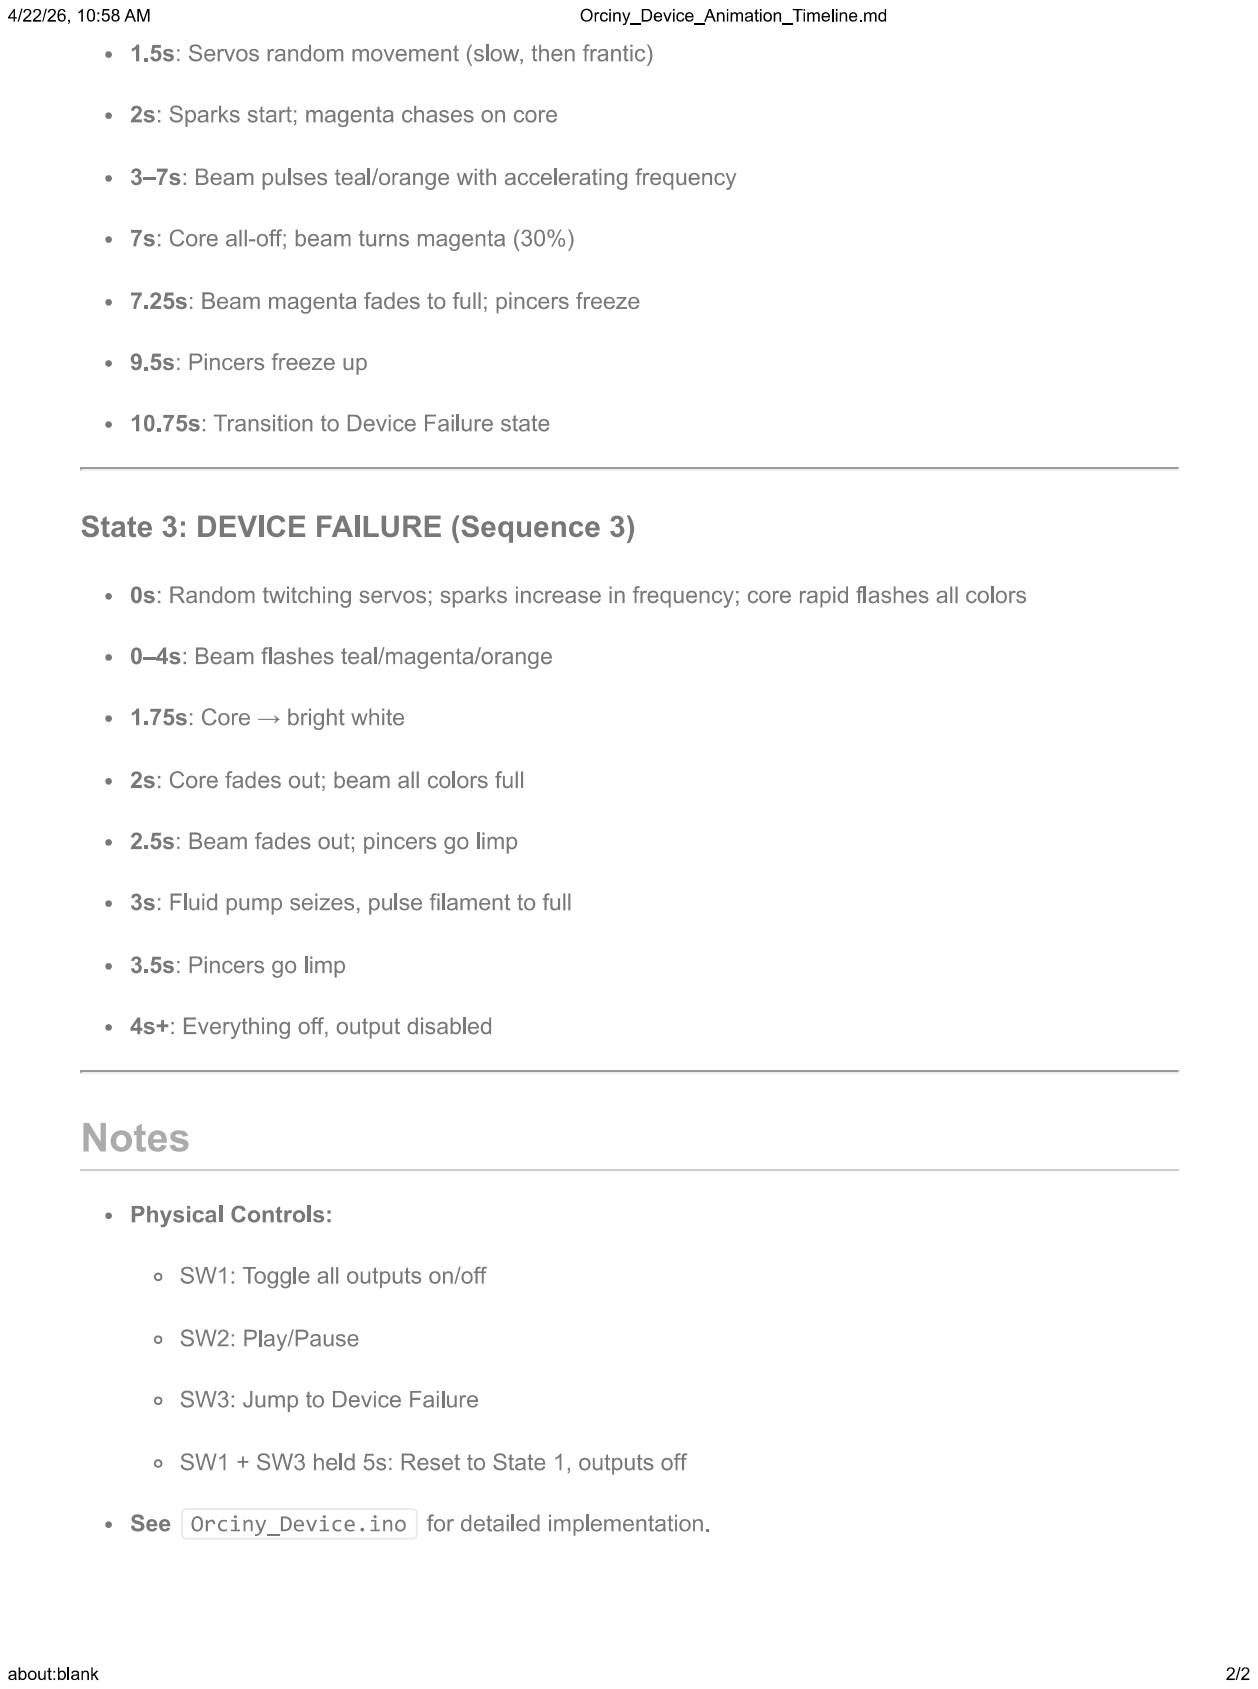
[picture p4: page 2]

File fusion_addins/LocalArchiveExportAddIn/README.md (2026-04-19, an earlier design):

# LocalArchiveExportAddIn (Fusion Add-In)

Adds a persistent toolbar command in Fusion to export the active design to your local archive.

## Install In Fusion

1. Open Fusion 360.
2. Go to Utilities > Scripts and Add-Ins.
3. Open the Add-Ins tab.
4. Click the + icon (Add-Ins from folder).
5. Select this folder:
   - `Orciny-Device/fusion_addins/LocalArchiveExportAddIn`
6. Select LocalArchiveExportAddIn and click Run.
7. Optional: enable Run on Startup.

## Where The Button Appears

The add-in adds two commands to a supported panel in the Design/Render workspaces:

- **Local Archive Export**
- **Local Archive Export + Box Sync**

## Config

Edit `archive_config.json` in this add-in folder:

- `exportRoot`: absolute export root path (empty means prompt on first run)
- `formats`: list of `f3d`, `step`, `stl`
- `stlOneFilePerBody`: `true` or `false`
- `createTimestampRunFolder`: `true` or `false`
- `boxSyncScriptPath`: PowerShell script path for Box sync (absolute or relative to add-in folder)
- `boxSyncArgs`: argument array passed to that script

Default Box sync args are:

- `-Mode RepoToBox -PruneLegacyDuplicates`

If the add-in folder is moved outside this repo, update `boxSyncScriptPath` accordingly.

## Output Layout

When timestamp folders are enabled:

- `<exportRoot>/run-YYYYMMDD-HHMMSS/<DocumentName>/<DocumentName>.f3d`
- `<exportRoot>/run-YYYYMMDD-HHMMSS/<DocumentName>/<DocumentName>.step`
- `<exportRoot>/run-YYYYMMDD-HHMMSS/<DocumentName>/<DocumentName>.stl`

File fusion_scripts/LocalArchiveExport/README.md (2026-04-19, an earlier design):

# LocalArchiveExport (Fusion Script)

This package can be imported in Fusion 360 using Scripts and Add-Ins.

## What It Does

- Exports the active Fusion design to a local archive folder.
- Supports `f3d`, `step`, and `stl` output formats.
- Creates a timestamped run folder by default.

## Import In Fusion

1. Open Fusion 360.
2. Go to Utilities > Scripts and Add-Ins.
3. In Scripts, click the + icon (Add script from folder).
4. Select this folder:
   - `Orciny-Device/fusion_scripts/LocalArchiveExport`
5. Select LocalArchiveExport and click Run.

## First Run

- On first run, the script asks you to choose an export root folder.
- That folder is saved to `archive_config.json`.

## Config

Edit `archive_config.json`:

- `exportRoot`: absolute folder path for exports
- `formats`: list of `f3d`, `step`, `stl`
- `stlOneFilePerBody`: `true` or `false`
- `createTimestampRunFolder`: `true` or `false`

## Output Layout

When timestamp folders are enabled:

- `<exportRoot>/run-YYYYMMDD-HHMMSS/<DocumentName>/<DocumentName>.f3d`
- `<exportRoot>/run-YYYYMMDD-HHMMSS/<DocumentName>/<DocumentName>.step`
- `<exportRoot>/run-YYYYMMDD-HHMMSS/<DocumentName>/<DocumentName>.stl`

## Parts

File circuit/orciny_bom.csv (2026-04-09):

Reference | Qty | Description | Value/Specification | Package | Preferred Source | Source Part # | Notes
U101 | 1 | Adafruit Feather RP2040 | ARM Cortex-M0+ 125MHz 4MB Flash RP2040 | Feather | Adafruit | 4884 | FX executor controller
U201 | 1 | Adafruit Feather M0 Basic Proto | ARM Cortex-M0+ 256KB Flash SAMD21 | Feather | Adafruit | 2772 | Primary scene controller (legacy split-controller reference)
F801 | 1 | SMD Slow-Blow Fuse 3A | +5V_BUS main branch protection | 1206 SMD | McMaster-Carr | Search: 1206 SMD slow-blow fuse 3A | Direct 5V rail for Servo FeatherWing and Prop-Maker/peltier load domain
R601 | 1 | Resistor 10Ω 1/4W Thick Film | SPARK1 channel series limiter | 0805 SMD | Seeed Studio | Search: 0805 10 ohm SMD resistor | Series protection on spark filament 1
R602 | 1 | Resistor 10Ω 1/4W Thick Film | SPARK2 channel series limiter | 0805 SMD | Seeed Studio | Search: 0805 10 ohm SMD resistor | Series protection on spark filament 2
R603 | 1 | Resistor 10Ω 1/4W Thick Film | SPARK3 channel series limiter | 0805 SMD | Seeed Studio | Search: 0805 10 ohm SMD resistor | Series protection on spark filament 3
R604 | 1 | Resistor 10Ω 1/4W Thick Film | SPARK4 channel series limiter | 0805 SMD | Seeed Studio | Search: 0805 10 ohm SMD resistor | Series protection on spark filament 4
R701 | 1 | Resistor 10Ω 1/4W Thick Film | BEAM_R channel series limiter | 0805 SMD | Seeed Studio | Search: 0805 10 ohm SMD resistor | Series protection on beam red leg for dedicated 3.7V LP503562 supply operation
R702 | 1 | Resistor 10Ω 1/4W Thick Film | BEAM_G channel series limiter | 0805 SMD | Seeed Studio | Search: 0805 10 ohm SMD resistor | Series protection on beam green leg for dedicated 3.7V LP503562 supply operation
R703 | 1 | Resistor 10Ω 1/4W Thick Film | BEAM_B channel series limiter | 0805 SMD | Seeed Studio | Search: 0805 10 ohm SMD resistor | Series protection on beam blue leg for dedicated 3.7V LP503562 supply operation
SW1 | 1 | Momentary Push Button 6mm | Toggle sequence ON/OFF; M0 D2 to GND | Through-hole | Adafruit | 1119 | INPUT_PULLUP; debounce 30ms in firmware
SW2 | 1 | Momentary Push Button 6mm | Previous sequence; M0 D3 to GND | Through-hole | Adafruit | 1119 | INPUT_PULLUP
SW3 | 1 | Momentary Push Button 6mm | Next sequence; M0 D4 to GND | Through-hole | Adafruit | 1119 | Hold SW1+SW3 5s to reset to seq 1
Q6 | 1 | N-Channel Logic-Level MOSFET | BEAM_R gate driver GP12 | TO-220 | Adafruit | 355 | Same as Q1
Q7 | 1 | N-Channel Logic-Level MOSFET | BEAM_G gate driver GP13 | TO-220 | Adafruit | 355 | Same as Q1
Q8 | 1 | N-Channel Logic-Level MOSFET | BEAM_B gate driver GP13 | TO-220 | Adafruit | 355 | Same as Q1
Q9 | 1 | N-Channel Logic-Level MOSFET | Peltier enable gate GP8; verify current rating | TO-220 | McMaster-Carr | Search: N-channel logic-level MOSFET TO-220 10A+ | Rate to the selected 5V peltier module peak current with thermal margin
Q10 | 1 | N-Channel Logic-Level MOSFET | Pump enable gate GPIO unassigned in this revision; 1-2A rating min | TO-220 | Adafruit | 355 | Optional 5V peristaltic pump path; assign a free GPIO if pump control is later enabled
J801 | 1 | 5V Power Connector | 5V battery input receptacle (JST XT60 or barrel jack) | Connector | Adafruit | 373 | Mates with 5V rechargeable battery pack or bench supply
J802 | 1 | 4-Pin 0.1in Header | Power distribution hub connector | 0.1in pitch THT | Adafruit | 392 | +5V_BUS / RP2040_BAT / +3V7_NEO / GND outputs
J811 | 1 | 2-Pin JST PH Connector | RP2040 main battery input | JST PH 2mm THT | Adafruit | 261 | PKCell LP503562 3.7V 1200mAh cell connected directly to Feather RP2040 BAT input (built-in Feather charging)
J812 | 1 | 2-Pin JST PH Connector | NeoPixel battery input | JST PH 2mm THT | Adafruit | 261 | Dedicated PKCell LP503562 3.7V 1200mAh cell to +3V7_NEO rail
U812 | 1 | Adafruit Micro Lipo Charger | Single-cell LiPo charger (USB input) | Breakout | Adafruit | 259 | Assigned to LP503562 NeoPixel battery only (CHG_NEO)
J601 | 1 | 5-Pin 0.1in Header | Filament PWM bus input (SPARK1-4 + GND) | 0.1in pitch THT | Adafruit | 392 | From RP2040 GP7/6/9/24 + GND
J603 | 1 | 4-Pin 0.1in Header | Filament load channel outputs (SPARK1-4) | 0.1in pitch THT | Adafruit | 392 | Post-resistor outputs to spark LED filament loads
J701 | 1 | 4-Pin 0.1in Header | Beam RGB PWM input bus (R/G/B + GND) | 0.1in pitch THT | Adafruit | 392 | From RP2040 GP11/12/13 + GND
J702 | 1 | 4-Position 3.5mm Screw Terminal | Beam RGB LED load output | 3.5mm screw terminal | Adafruit | 677 | Post-resistor outputs to high-power RGB LED
J703 | 1 | 2-Pin JST PH Connector | Peltier load output | JST PH 2mm THT | Adafruit | 261 | Switched 5V to peltier module via Q9
J401 | 1 | 2-Pin JST PH Connector | 5V peristaltic pump output | JST PH 2mm THT | Adafruit | 261 | From Q10 MOSFET drain via +5V_BUS to pump terminals
J402 | 1 | 3-Pin 0.1in Header or JST | Servo signal connector (replaces stepper) | 0.1in pitch | Adafruit | 392 | GP7 signal + 5V_BUS + GND for FP-S14B
— | 1 | FP-S14B Claw Servo | Standard RC servo; 6V max operation | Standard RC servo | Seeed Studio | Search: FP-S14B servo | GP7 signal from RP2040; power from +5V_BUS
— | 1 | 5V Peristaltic Pump | DC motor liquid pump 3V-6V | 2-wire | Adafruit | 1150 | Direct GPIO control via Q10; +5V_BUS supply
— | 1 | 5V Peltier Module | 5V thermoelectric cooler module sized to the +5V_BUS budget | 40x40mm | Grainger | Search: 5V peltier module | Q9 switch rating must match selected module current; heatsink required on both faces
— | 4 | Spark LED Filament | Incandescent-style LED filament matched to the direct GPIO design | Custom | Adafruit | Search: LED filament strip | Series R601-R604; validate current draw against RP2040 GPIO limits before assembly
— | 1 | 3-9W High-Power RGB LED | Star-format or module RGB LED for beam | Star PCB module | Seeed Studio | Search: 3W RGB LED star module | R/G/B legs through Q6-Q8 and R701-R703; powered from +5V_BUS Prop-Maker supply domain; heatsink required
— | 1 | Electrolytic Capacitor | NeoPixel strip input bulk capacitor | 500-1000uF 6.3V or higher radial | Radial electrolytic | Adafruit | Search: 1000uF electrolytic capacitor | Mount across +3V7_NEO and GND at first pixel power entry to absorb startup and load transients
— | 1 | NeoPixel LED Strip 166 LEDs SK6812 | Addressable RGB strip with 166 pixels; 5V nominal operation | SK6812 strip | Adafruit | 4865 | Single data line to RP2040 GP4; powered from dedicated +3V7_NEO rail; firmware enforces 2A max strip current guard rail
— | 1 | 5V Battery Pack or Bench Supply | Main 5V input source sized for ServoWing and Prop-Maker/peltier loads | Wall adapter or battery pack | Adafruit | Search: 5V battery pack or 5V bench supply | Supply only for +5V_BUS wing/load domain
— | 2 | PKCell LP503562 LiPo Battery | 3.7V 1200mAh single-cell pouch battery | LP503562 | PKCell | LP503562 | Cell #1 direct to Feather RP2040 BAT (built-in charging); cell #2 dedicated to +3V7_NEO with external Adafruit 259 charger; tie negatives to GND_COMMON

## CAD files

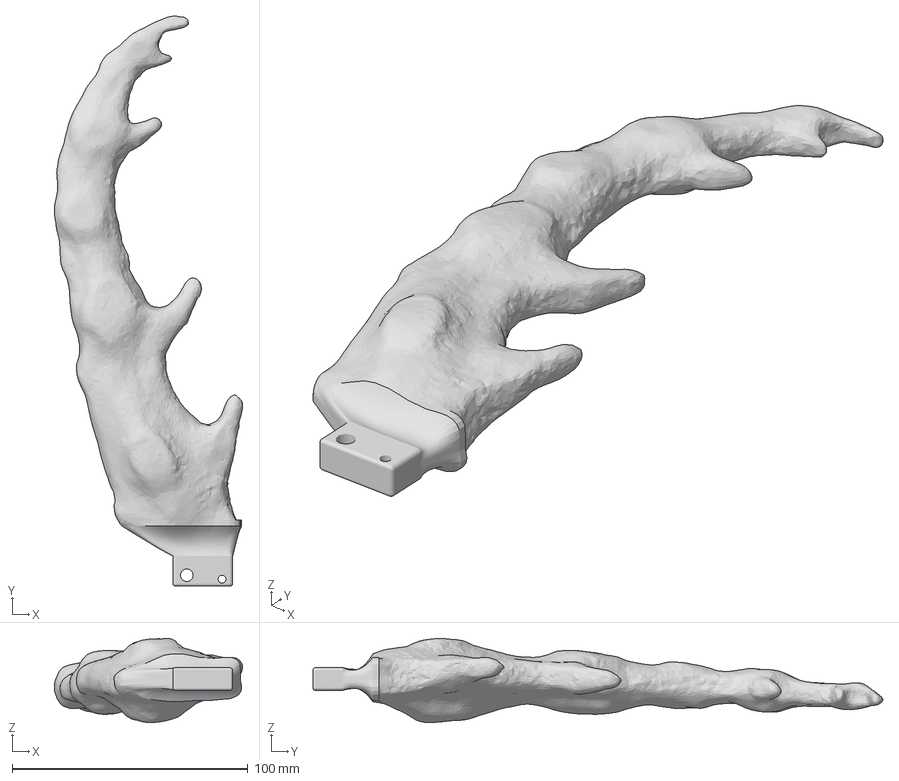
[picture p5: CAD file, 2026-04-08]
3d Models/Pincer 4.3.3mf
79.8 x 241.9 x 35.7 mm

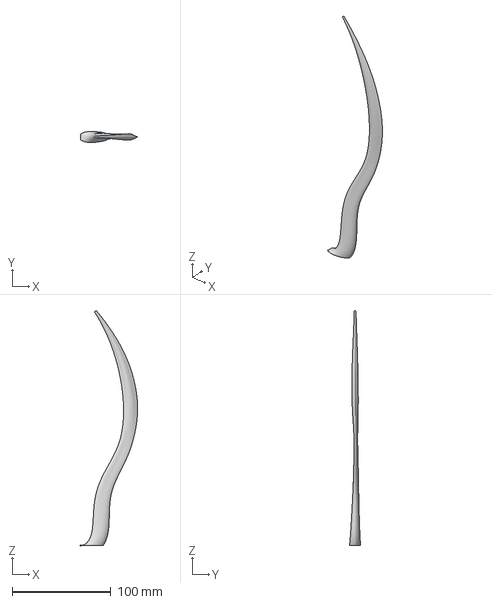
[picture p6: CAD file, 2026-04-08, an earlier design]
3d Models/Archive/Pincer Mesh.3mf
58.1 x 11.3 x 238.2 mm

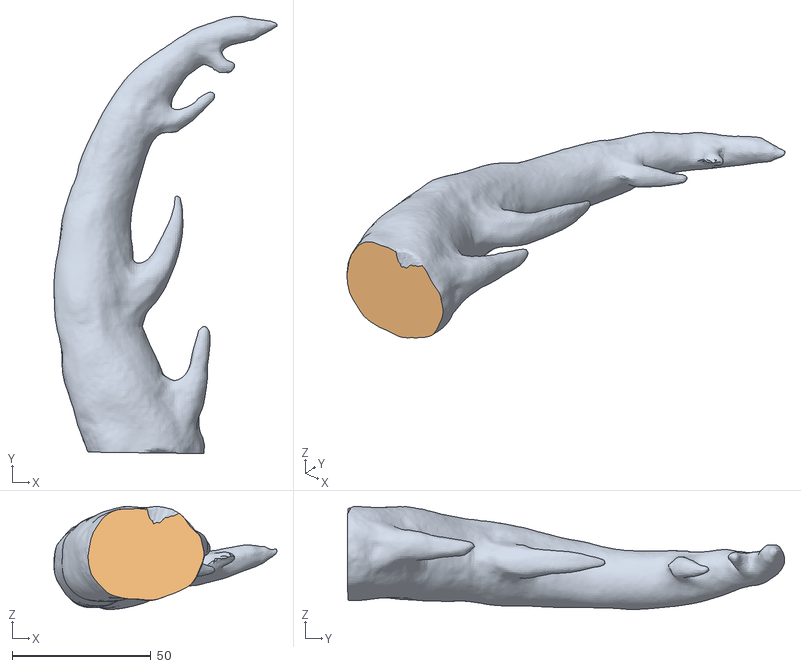
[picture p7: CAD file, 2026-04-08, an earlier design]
3d Models/Archive/Clay pincer meshmodel.obj
80.3 x 157.4 x 37.2
mmGroup0
mmGroup2

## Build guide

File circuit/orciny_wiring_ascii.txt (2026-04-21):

ORCINY DEVICE - ASCII CIRCUIT DIAGRAM
======================================
Rev F  (RP2040-only control; split battery domains)

Harness cross-reference: see `circuit/orciny_wiring_harness_reference.md`.

Power:
  Harness IDs: H-PWR-5V, H-BAT-RP, H-BAT-NEO
  5V battery (J801)  -> main fused input -> +5V_MAIN trunk
  +5V_MAIN trunk     -+-> F801 (direct) -------- +5V_BUS rail (ServoWing + Prop-Maker/peltier load domain)
  3.7V battery (J811, PKCell LP503562 1200mAh) -> Feather RP2040 BAT input (controller + spark domain)
  NeoPixel strip supply (current profile): +5V_BUS rail
  Legacy optional path: Adafruit 259 charger (U812, CHG_NEO) -> LP503562 battery at J812 -> +3V7_NEO rail

  +5V_BUS rail       -> Servo FeatherWing/load supply, Prop-Maker LED load supply, peltier source domain
  RP2040_BAT rail    -> RP2040 logic supply and direct spark filament source domain
  +3V7_NEO rail      -> legacy optional NeoPixel-only rail
  GND_COMMON         -> COMMON to every board, switch, driver, and load

  Note: if legacy +3V7_NEO is used, only the NeoPixel battery uses external Adafruit 259 charging; the RP2040 battery uses Feather onboard charging.

 5V BATTERY
 (J801 connector or barrel jack)
       |
       | +5V_MAIN
     [Main fuse]
       |
       +---- F801 (3A) -------- +5V_BUS ----+
                                             |
         +-----------------------------------+
         | +5V_BUS (ServoWing + Prop-Maker/peltier load domain)
         v

 ┌─────────────────────────────────────────────────────────────────┐
 │                      FEATHER RP2040                             │
 │                    Primary Scene + FX Node                      │
 │                                                                 │
 │  A1/A2/A3     <------------------------- SW1/SW2/SW3            │
 │  GP25 (NeoPixel data) -----------------> NeoPixel strip DI      │
 │                                                                 │
 │  GP18 PWM ---> [R601 10Ω] ---> Spark Filament 1                │
 │  GP19 PWM ---> [R602 10Ω] ---> Spark Filament 2                │
 │  GP20 PWM ---> [R603 10Ω] ---> Spark Filament 3                │
 │  GP24 PWM ---> [R604 10Ω] ---> Spark Filament 4                │
 │                                                                 │
 │  GP11 PWM ---> Prop-Maker LED1 MOSFET out ---> 3-9W LED CH1    │
 │  GP12 PWM ---> Prop-Maker LED2 MOSFET out ---> 3-9W LED CH2    │
 │  GP13 PWM ---> Prop-Maker LED3 MOSFET out ---> 3-9W LED CH3    │
 │                                                                 │
 │  I2C SDA/SCL ---------------------------> Servo FeatherWing     │
 │                                           (PCA9685 @ 0x40)      │
 │  GP1  (Pump MOSFET gate) ---> Pump MOSFET gate (on/off control) │
 └─────────────────────────────────────────────────────────────────┘
   │  GP0  PWM ---> [R605 10Ω] ---> Pulse Fila                                  │
   │  Harness ID: H-PULSE-FILAMENT             ment (dedicated PWM control)      │
  │                                                                            │
   │  Pulse Filament Channel (optional):                                      │
   │                                                                            │
   │  GP0  (Pulse Filament PWM) ---> [R605 10Ω] ---> Pulse Filament load      │
   │  RP2040_BAT domain supply                                                  │
   │  Return: GND_COMMON                                                        │
   │  Use 22-24 AWG for signal, 20 AWG for power/return if needed             │
  │                                                                            │
 Pulse Filament Channel (optional):
 Harness ID: H-PULSE-FILAMENT

  GP0  (Pulse Filament PWM) ---> [R605 10Ω] ---> Pulse Filament load
  RP2040_BAT domain supply
  Return: GND_COMMON
  Use 22-24 AWG for signal, 20 AWG for power/return if needed
  +5V_BUS (NeoPixel strip power)
       |
       v
 ┌──────────────────────────────┐
 │  SK6812 NeoPixel Strip       │
 │  166 pixels (single strand)  │
 │  Data <-- RP2040 GP25        │
 │  +V   <-- +5V_BUS            │
 │  GND  --> GND_COMMON         │
 └──────────────────────────────┘

 ┌──────────────────────────────────────────────┐
 │     8-Channel Servo FeatherWing (PCA9685)   │
 │                                              │
 │  I2C from RP2040: SDA, SCL, GND             │
 │  V+ from +5V_BUS (servo power domain)       │
 │                                              │
 │  CH0 PWM ---> Servo A signal                │
 │  CH1 PWM ---> Servo B signal                │
 │                                              │
 │  Servo A +5V/GND from +5V_BUS/GND_COMMON    │
 │  Servo B +5V/GND from +5V_BUS/GND_COMMON    │
 └──────────────────────────────────────────────┘

  Note: Feather Doubler/Tripler sockets are cross-connected. Header nets are
  shared between Feather and both wings (GPIO pins are not isolated).

 ┌──────────────────────────────────────────────┐
 │       Prop-Maker FeatherWing (LED Driver)   │
 │                                              │
 │  LED1/LED2/LED3 are MOSFET-switched outputs │
 │  for the high-power 3-9W LED channels.      │
 │                                              │
 │  Input control from RP2040 GP11/12/13       │
 │  PWR enable from RP2040 GP10 (held HIGH)    │
 │  Power from +5V_BUS, return to GND_COMMON   │
 └──────────────────────────────────────────────┘

 Switches (momentary, wired to GND; firmware uses INPUT_PULLUP):
 Harness ID: H-SW
 ┌────────┐        ┌────────┐        ┌────────┐
 │  SW1   │        │  SW2   │        │  SW3   │
 │ On/Off │        │  Prev  │        │  Next  │
 └───┬────┘        └───┬────┘        └───┬────┘
     |                 |                 |
 RP2040 A1(GP27)    RP2040 A2(GP28)    RP2040 A3(GP29)
   GND               GND               GND
   Hold SW1 + SW3 together for 5s -> reset to sequence 1

 Direct Spark Filament Stage:
 Harness ID: H-SPARK

   RP2040 GPIO pin
         |
   [10 ohm series resistor]
         |
   Spark filament channel

  Spark branch is supplied from RP2040_BAT in this revision.

 MOSFET Driver Stage (beam / peltier / optional pump paths):
 Harness IDs: H-BEAM-PWR, H-PELTIER-PWR, H-PUMP-OPT
 (GP11/12/13 beam control, GP10 PWR enable, and GP8 peltier control route through FeatherWing stack headers; not separately harnessed)

  Firmware thermal behavior:
    GP8 drives Q9 for peltier control.
    Peltier turns ON while beam is enabled and remains ON briefly after beam turns OFF for heat dissipation.

   RP2040 GPIO pin
         |
     (gate)  N-channel MOSFET (logic-level, Vgs(th) < 2.5V)
         |
   drain -- Load negative terminal
   source -- GND_COMMON

  Load positive terminal -- +5V_BUS (beam/peltier domain)
  Pump load positive terminal -- +5V_BUS

 Spark Filament Channels (J601 -> R601-R604 -> J603):
 Harness ID: H-SPARK

  RP2040_BAT domain -> spark supply source (direct GPIO channels)
  J601 PWM bus -> R601 10Ω -> Spark Filament 1 load (GP18)
   J601 PWM bus -> R602 10Ω -> Spark Filament 2 load (GP19)
   J601 PWM bus -> R603 10Ω -> Spark Filament 3 load (GP20)
   J601 PWM bus -> R604 10Ω -> Spark Filament 4 load (GP24)

 Prop-Maker LED Outputs (3-9W LED):
 Harness ID: H-BEAM-PWR
 (GP11/12/13 control signals and GP10 PWR enable enter Prop-Maker via stacked header; not a separate cable harness)

  +5V_BUS powers the Prop-Maker LED output stage
  RP2040 GP11/12/13 provide control for LED1/LED2/LED3 channels
  RP2040 GP10 must be held HIGH to enable Prop-Maker LED outputs
  LED load returns to GND_COMMON

  Peltier load is sourced from the Prop-Maker 5V supply domain.

Pump Channel:
Harness ID: H-PUMP

  GP1 (Pump MOSFET gate) ---> N-channel MOSFET gate
  MOSFET drain ---> Pump negative terminal
  MOSFET source ---> GND_COMMON
  Pump positive terminal ---> +5V_BUS
  Add flyback diode across pump terminals (cathode to +5V, anode to MOSFET drain)

 Power Domain Summary:
   Rail              Source               Protected By   Consumers
   +5V_BUS           Direct from 5V bat   F801 (3A)      Servo FeatherWing + servos, Prop-Maker load stage, peltier, optional pump
   RP2040_BAT        LP503562 cell #1     Feather onboard controller supply, direct spark filament branch (Spark 1-4)
  CHG_NEO           Adafruit 259 (U812)  Charger IC     Legacy optional Neo battery path only
  +3V7_NEO          LP503562 cell #2     Legacy optional NeoPixel-only rail

 Wire Gauge Guidance (high-current runs):
   +5V_MAIN and +5V_BUS trunk wiring: use 18 AWG minimum.
  High-current branch feeds and returns (+5V_BUS to NeoPixel/servo wing/Prop-Maker/peltier, RP2040_BAT spark branch): use 20 AWG minimum.
   Keep GND return wiring for each high-current branch at the same gauge as its positive feed.
   Signal/control lines (GPIO, I2C, serial, switch leads): 24-26 AWG is acceptable.
   If a branch run is long or heating is observed, step one gauge larger and re-validate thermal rise under peak load.
   Use a local inline fuse at each LP503562 battery positive lead near the cell.

 Quick Net Summary:
   Harness map:
   H-PWR-5V    -> +5V input trunk and +5V_BUS load backbone
   H-BAT-RP    -> J811 RP2040 BAT battery run
  H-BAT-NEO   -> optional legacy J812 NeoPixel battery and U812 charger pair
   H-CORE      -> NeoPixel data/power/ground run
   H-SW        -> switch inputs to controller
   H-SPARK     -> spark PWM channels and returns
  H-SERVO     -> ServoWing outputs and power/ground branches (I2C enters via stacked header)
  H-BEAM-PWR  -> +5V_BUS beam load-side feed
  H-PELTIER-PWR -> +5V_BUS peltier load-side feed
   H-PUMP-OPT  -> optional pump control/load branch

   RP2040 A1(GP27) <- SW1 -> GND   (toggle ON/OFF)
   RP2040 A2(GP28) <- SW2 -> GND   (previous sequence, 1->3 wrap)
   RP2040 A3(GP29) <- SW3 -> GND   (next sequence, 3->1 wrap)
  RP2040 GP25  -> NeoPixel strip data (166 pixels, SK6812, Adafruit 4865, single strand)
   J811         -> RP2040 Feather BAT input (main 3.7V controller/spark battery)
  U812         -> optional legacy charger for J812 LP503562 battery (+3V7_NEO)
  +5V_BUS      -> NeoPixel strip +V (current profile)
   +5V_BUS      -> Prop-Maker load supply and peltier source domain
  RP2040 GP18/GP19/GP20/GP24 -> direct spark filament outputs (R601-R604)
  RP2040 GP10      -> Prop-Maker PWR enable (held HIGH)
  RP2040 GP11-GP13 -> Prop-Maker LED1/LED2/LED3 channel control
  RP2040 GP8       -> peltier MOSFET gate (auto beam-follow + cooldown hold)
   RP2040 SDA/SCL   -> Servo FeatherWing (PCA9685 @ 0x40)
   Servo Wing CH0/1 -> Servo A / Servo B signal lines
   Pump GPIO        -> unassigned in this revision (GP8 reassigned to peltier)
   Hold SW1 + SW3 for 5s => reset to sequence 1

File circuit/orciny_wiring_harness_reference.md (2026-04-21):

### H-PULSE-FILAMENT - Pulse Filament Harness
- Harness Label 10
- Channel: RP2040 GP0 (PWM) -> [R605 10Ω] -> Pulse Filament load
- Supply domain: RP2040_BAT
- Return: GND_COMMON
- Recommended wire: 22-24 AWG signal, 20 AWG power/return if needed
- Notes: Dedicated PWM control for pulse filament effect. Label both ends as H-PULSE-FILAMENT.
# Orciny Wiring Harness Reference

This file groups cable runs into practical harness bundles for assembly and troubleshooting.

Design intent in this reference:
- RP2040 is the primary controller.
- Feather wings stack directly on the RP2040 Feather, so no interconnect harness is required between the controller and stacked wings.
- On a Feather Doubler/Tripler, header nets are electrically shared across sockets (GPIO pins are not isolated between wings).
- Main 5V rail powers only ServoWing and Prop-Maker/peltier load domains.
- One LP503562 battery feeds RP2040 BAT directly.
- NeoPixel strip is powered from +5V_BUS and data is driven from RP2040 GP25.

## Harness Set Overview

| Harness ID | Name | Scope | Notes |
|---|---|---|---|
| H-PWR-5V | 5V load backbone | Main 5V input to +5V_BUS load domain | Feeds stacked wings and other +5V load branches. |
| H-BAT-RP | RP2040 battery harness | Main 3.7V battery to Feather BAT | Feather onboard charger handles this pack. |
| H-BAT-NEO | NeoPixel battery + charger harness | Optional legacy Neo battery/charger wiring | Use only if retaining dedicated +3V7_NEO architecture. |
| H-CORE | NeoPixel strip harness | Data and strip supply run | Keep data conductor separated from noisy load wiring. |
| H-SW | Switch input harness | SW1/SW2/SW3 to controller inputs | Shared ground return. |
| H-SPARK | Spark output harness | RP2040 spark PWM channels to spark loads | DMX cable runs down shaft; pins 1-4 are Spark 1-4, pin 5 is spare if needed, and GND is common. |
| H-SERVO | Servo output harness | ServoWing outputs and power out to servos | ServoWing stacks on the Feather, so no separate Feather-to-wing harness is needed. |
| H-BEAM-PWR | Beam load harness | +5V_BUS load-side runs to beam path | Prop-Maker FeatherWing stacks on the Feather; harness is beam load-side wiring only. |
| H-PELTIER-PWR | Peltier load harness | +5V_BUS load-side runs to peltier path | Separate high-current branch for peltier load wiring. |

## Harness Definitions

### H-PWR-5V - 5V Load Backbone
- Harness Label 1
- Source: J801 (5V input)
- Path: Main fuse -> F801 -> +5V_BUS
- Loads: Servo FeatherWing V+, Prop-Maker load domain, optional pump/peltier load supply
- Recommended wire: 18 AWG trunk, 20 AWG branches
- Notes: Keep this harness physically separated from low-level signal bundles.

### H-BAT-RP - RP2040 Battery Harness
- Harness Label 10
- Source: LP503562 cell #1
- Destination: Feather RP2040 BAT and GND
- Charging: Feather onboard charger path
- Recommended wire: 20 AWG
- Notes: Keep battery positive isolated from +5V_BUS and +3V7_NEO.
- Battery connects directly to Feather's Battery JST port

### H-BAT-NEO - NeoPixel Battery and Charger Harness
- Harness Label 2
- Source: LP503562 cell #2
- Charger: U812 (Adafruit 259)
- Destination rail: +3V7_NEO (legacy optional path)
- Recommended wire: 20 AWG battery and rail runs
- Notes: U812 output must remain dedicated to this battery/rail pair only.
- Add a 500-1000 uF bulk electrolytic capacitor across +3V7_NEO and GND at the strip power entry point.
- Use 2 pin JST for power to Charger output
- Red wire is positive, black wire is negative

### H-CORE - NeoPixel Strip Harness
- Harness Label 3
- Signal run: RP2040 GP25 -> strip DI
- Power run: +5V_BUS -> strip +V
- Ground run: GND_COMMON -> strip GND
- Recommended wire: 24-26 AWG for data, 20 AWG for strip power/ground
- Notes: Keep data conductor away from high-current switching runs where possible.
- Place the bulk capacitor physically close to the first pixel / strip power injection point.
- Use 2 pin JST for signal + ground to microcontroller
- White wire is signal, brown wire is common

- Note for NeoPixel harnesses: I am using a 4 pin cable. On the neopixel side, I am using a 3 pin JST HX to combine signal and power. Pin one (red) is power, pin two (white) is signal, pin 3 (black and brown spliced) is common. A capacitor is bridging power and common. This is Harness 2/3. The cable splits into two sets of two and becomes harness 2 and harness 3. 

### H-SW - Switch Input Harness
- Harness Label 4
- SW1 -> RP2040 A1 (GP27)
- SW2 -> RP2040 A2 (GP28)
- SW3 -> RP2040 A3 (GP29)
- Return: shared GND
- Recommended wire: 24-26 AWG
- Notes: Route this harness away from spark and servo power runs.
- use 4 pin JST connector
- Pin 1 (blue) is SW1, pin 2 (brown) is SW2, pin 3 (orange) is SW3, and pin 4 (green) is common

### H-SPARK - Spark Output Harness
-- Harness Label 5
- Channels: RP2040 GP18/GP19/GP20/GP24 (through series resistors) -> Spark 1-4
- Supply domain: RP2040_BAT
- Return: GND_COMMON
- Recommended wire: 22-24 AWG signal legs, 20 AWG shared feed/return where applicable
- Notes: Keep channel labeling fixed end-to-end to avoid cross-wiring.
- Use 5 pin DMX cable
- Green is common, pins 1 (red), 2 (brown), 3 (white), and 4 (blue) are the individual positive connections for the sparks, and pin 5 (black) is a spare

### H-SERVO - Servo Output Harness
- Harness Label 6
- Stack note: ServoWing stacks directly on the Feather RP2040; SDA/SCL, control, and wing power are handled by the stack headers.
- Output runs: ServoWing CH0 -> Servo A signal, CH1 -> Servo B signal
- Power runs: ServoWing V+ and GND -> servo power branches
- Recommended wire: 24-26 AWG for signal, 20 AWG for power/ground branches
- Notes: Match positive and return gauge on each servo branch; no separate Feather-to-ServoWing harness is required.
- Use 4 pin JST connector
- Pin 1 (white) is CH0 signal, Pin 2 (blue) is CH1 signal, Pin 3 (red) is power, pin 4 (black) is common

### H-BEAM-PWR - Beam Load Harness
- Harness Label 7
- Stack note: Prop-Maker FeatherWing stacks directly on the Feather RP2040; no separate controller-to-wing harness is required.
- Control note: RP2040 GP10 (D10) is reserved for Prop-Maker PWR enable and must be held HIGH.
- Thermal note: firmware asserts RP2040 GP8 peltier control while beam is active and keeps peltier on for a short post-beam cooldown hold.
- +5V_BUS -> Prop-Maker load domain and beam load source path
- GND_COMMON return from beam load stage
- Recommended wire: 20 AWG minimum
- Notes: Treat as high-current branch and keep runs short; this harness is beam load-side only.
- Beam should have 4 pin JST connector
- Beam LED chip is common anode. Connector pins are pin 1 (white) as common anode, pin 2 (red) as red channel, pin 3 (blue) as blue channel, pin 4 (green) as green channel

### H-PELTIER-PWR - Peltier Load Harness
- Harness Label 8
- Stack note: Prop-Maker FeatherWing stacks directly on the Feather RP2040; no separate controller-to-wing harness is required.
- Control: RP2040 GP8 -> Q9 peltier MOSFET gate.
- +5V_BUS -> peltier load source path
- GND_COMMON return from peltier load stage
- Recommended wire: 20 AWG minimum
- Notes: Keep this as a separate high-current branch for thermal control load wiring. Firmware behavior is auto-managed: peltier ON with beam, then held ON briefly after beam turns OFF for heat dissipation.
- Peltier uses Deans Micro2R connector
- Pin 1 (red) is power, pin 2 (black) is common

### H-SIGNAL - GP0/GP1 Signal Harness
- Harness Label 9
- Signal runs: RP2040 GP0 (blue), RP2040 GP1 (green)
- Use 24-26 AWG wire
- Notes: This harness carries logic-level signals only. Label both ends as H-SIGNAL.

- Harness Label 11
- Power runs: +5V_BUS to pump positive terminal, GND_COMMON to pump negative terminal (via MOSFET)
- Use 20 AWG wire for power, 24-26 AWG for control if needed
- Notes: This harness carries the main pump load current. Label both ends as H-PUMP-POWER.

## Labeling Convention

Use heat-shrink or tags at both ends:
- Harness ID (example: H-CORE)
- Net name (example: GP25_DI, +5V_BUS, GND)
- Channel index for multi-channel runs (SP1..SP4)

## Bring-Up Continuity Checklist

1. Verify no short between +5V_BUS and RP2040_BAT.
2. If using the legacy Neo battery path, also verify no short to +3V7_NEO.
3. Verify all grounds share continuity to GND_COMMON.
4. Verify H-CORE data continuity from RP2040 GP25 to strip DI.
5. Verify H-SPARK channel mapping (GP18/19/20/24 to Spark 1/2/3/4).
6. Verify H-SERVO polarity before connecting servos.
7. Verify H-BEAM-PWR and H-PELTIER-PWR are not cross-connected.
8. If using legacy H-BAT-NEO, verify U812 charger wiring only touches the Neo battery rail.

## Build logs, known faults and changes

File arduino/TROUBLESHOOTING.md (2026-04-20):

# Arduino Setup And Troubleshooting

Version: V 0.3.7

This folder contains both sketches and local libraries used by the Orciny Device Arduino code.

If a sketch fails to compile after downloading the project, check these common issues:

1. Arduino IDE is not using the correct sketchbook path (should be set to the repo's `arduino` folder).
2. Local libraries are not in the correct folder structure (see below).
3. Required third-party libraries (Adafruit NeoPixel, Adafruit PWM Servo Driver, Adafruit BusIO) are not installed.
4. Arduino IDE needs to be restarted after library changes.

## Expected Folder Structure

Arduino should be able to find the local libraries with this layout:

```text
arduino/
  libraries/
    OrcinyCommon/
      library.properties
      src/
        OrcinyCommon.h
        ColorPalettes.h
        AnimationPalettes.h
    OrcinyEffects/
      library.properties
      src/
        OrcinyEffects.h
  rp2040_fx_starter/
    rp2040_fx_starter.ino
  rp2040_fx_controller_demo/
    rp2040_fx_controller_demo.ino
```

Important rule:

All public Arduino library headers must live in the library's `src` folder. For this project, `ColorPalettes.h` and `AnimationPalettes.h` belong in `libraries/OrcinyCommon/src/`, not beside the sketch.

## Recommended Arduino IDE Setup

Set Arduino IDE's Sketchbook location to the `arduino` folder in this repo.

Example:

```text
C:\Users\USERNAME\Box\Orciny Device\arduino
```

**Note (v1.0.0+):** Once this project reaches version 1.0.0 or later, reconfigure the folder structure out of Box and into the default Arduino sketchbook location (for example, `Documents\Arduino`).

In Arduino IDE:

1. Open `File > Preferences`.
2. Set `Sketchbook location` to this repo's `arduino` folder.
3. In `Additional Boards Manager URLs`, add:

```text
https://github.com/earlephilhower/arduino-pico/releases/download/global/package_rp2040_index.json
```

4. Click `OK` to save Preferences.
5. Open `Tools > Board > Boards Manager`.
6. Search for `Raspberry Pi Pico/RP2040`.
7. Install the `Raspberry Pi Pico/RP2040` package by Earle F. Philhower, III.
8. Restart Arduino IDE.

Why this matters:

Arduino automatically scans the sketchbook's `libraries` folder. If the sketchbook points somewhere else, includes such as `#include <ColorPalettes.h>` and `#include <AnimationPalettes.h>` will fail even if the files exist in the repo.

## Common Problems

### Error: `fatal error: ColorPalettes.h: No such file or directory`

Cause:

Arduino cannot see the `OrcinyCommon` library.

Fix:

1. Confirm your sketchbook path points to this folder's `arduino` directory.
2. Confirm `ColorPalettes.h` exists at `arduino/libraries/OrcinyCommon/src/ColorPalettes.h`.
3. Restart Arduino IDE.

### Error: `fatal error: AnimationPalettes.h: No such file or directory`

Cause:

Same root cause as above. Arduino is not resolving the `OrcinyCommon` library correctly.

Fix:

1. Check sketchbook path.
2. Check that `AnimationPalettes.h` exists at `arduino/libraries/OrcinyCommon/src/AnimationPalettes.h`.
3. Make sure there are not duplicate copies of these headers in sketch folders.

### Error: `Adafruit_PWMServoDriver.h: No such file or directory`

Cause:

The Adafruit PCA9685 servo driver library is missing.

Fix:

Install the library from Arduino Library Manager:

1. Open `Sketch > Include Library > Manage Libraries`.
2. Search for `Adafruit PWM Servo Driver Library`.
3. Install it.

### Error: `Adafruit_NeoPixel.h: No such file or directory`

Cause:

The Adafruit NeoPixel library is missing.

Fix:

Install `Adafruit NeoPixel` from Library Manager.

### Error related to `Adafruit_I2CDevice.h` or `Adafruit_BusIO`

Cause:

`Adafruit BusIO` is missing. Some Adafruit libraries depend on it.

Fix:

Install `Adafruit BusIO` from Library Manager.

### The files are present but Arduino still will not compile

Check these in order:

1. Folder names must match the library names exactly.
2. Public headers must be in the library `src` folder.
3. `library.properties` must exist in each custom library root.
4. Arduino IDE often needs a restart after moving library files.
5. If you copied the project manually, remove stale duplicate headers from sketch folders.

## Local Libraries In This Project

These libraries are intended to be used as local sketchbook libraries:

1. `OrcinyCommon`
2. `OrcinyEffects`

At the current stage, they do not need Arduino Library Manager publication. Local installation is simpler and avoids premature packaging overhead.

## When A Packaging Pass Makes Sense

Yes, it makes sense to plan a package version later, but not necessarily publish it yet.

That future packaging pass should happen when the APIs and folder layout have mostly stabilized. The useful goal is a release-ready package, not immediate distribution.

Recommended packaging targets:

1. `OrcinyCommon` as a standalone Arduino library package.
2. `OrcinyEffects` as a standalone Arduino library package.
3. Starter sketches kept as examples or templates outside the library packages.

Recommended pre-release checklist:

1. Freeze public header names and namespaces.
2. Verify all public headers live under `src/`.
3. Add or review `library.properties` metadata.
4. Confirm example sketches compile against the packaged libraries.
5. Add a short changelog and versioning policy.
6. Create ZIP artifacts for test installs with `Add .ZIP Library`.

Practical recommendation:

Do the packaging cleanup shortly before a broader handoff, first public share, or hardware beta. Until then, keep the repo optimized for active development.

### Error related to `Adafruit_I2CDevice.h` or `Adafruit_BusIO`

Cause:

`Adafruit BusIO` is missing. Some Adafruit libraries depend on it.

Fix:

Install `Adafruit BusIO` from Library Manager.

### The files are present but Arduino still will not compile

Check these in order:

1. Folder names must match the library names exactly.
2. Public headers must be in the library `src` folder.
3. `library.properties` must exist in each custom library root.
4. Arduino IDE often needs a restart after moving library files.
5. If you copied the project manually, remove stale duplicate headers from sketch folders.

## Local Libraries In This Project

These libraries are intended to be used as local sketchbook libraries:

1. `OrcinyCommon`
2. `OrcinyEffects`

At the current stage, they do not need Arduino Library Manager publication. Local installation is simpler and avoids premature packaging overhead.

## When A Packaging Pass Makes Sense

Yes, it makes sense to plan a package version later, but not necessarily publish it yet.

That future packaging pass should happen when the APIs and folder layout have mostly stabilized. The useful goal is a release-ready package, not immediate distribution.

Recommended packaging targets:

1. `OrcinyCommon` as a standalone Arduino library package.
2. `OrcinyEffects` as a standalone Arduino library package.
3. Starter sketches kept as examples or templates outside the library packages.

Recommended pre-release checklist:

1. Freeze public header names and namespaces.
2. Verify all public headers live under `src/`.
3. Add or review `library.properties` metadata.
4. Confirm example sketches compile against the packaged libraries.
5. Add a short changelog and versioning policy.
6. Create ZIP artifacts for test installs with `Add .ZIP Library`.

Practical recommendation:

Do the packaging cleanup shortly before a broader handoff, first public share, or hardware beta. Until then, keep the repo optimized for active development.

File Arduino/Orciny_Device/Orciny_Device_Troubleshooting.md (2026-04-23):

# Orciny Device Physical Troubleshooting Guide

**Version:** V 0.9.0

---

## Assembly notes:
- Device has two internal batteries, only one of which is typically accessable.
- The inaccessable battery is a 3.7V LiPO cell stack that is connected to the microcontroller in the cavity under the pincer nozzle and should remain connected at all times.
- The accessable battery is a 5V "power bank" style unit attached in the broken end of the device.
- External troubleshooting is available for crew work, but Device Team should be contacted for internal work.

## Charging:
- Please unplug 5V battery between shows
- Use attached USB cable located above the core of the device to charge the 3.7V battery
- Plug in a MicroUSB cable into the power bank to charge the 5V battery

- **Note**: It is likely that the 5V battery will last for multiple shows, especially if it is unplugged when not in use. 
    The 3.7V internal battery should be plugged in daily since it can not be disconnected from the controller and will slowly drain over time.

## Arduino Notes:
- This program is written in the Arduino IDE and includes status prints over USB
- If you connect the device to a computer running the Arduino IDE, you can get internal statuses in the Serial Monitor at Baud 115220
    - This inculdes button presses, current status, and current step

## 1. Power & Battery Issues
- **Check Battery Connection:**
  - Be sure that 5V battery is plugged in
- **Charge Battery:**
  - Confirm it is fully charged.
  - Try powering via USB to rule out battery issues.
- **Power Switch:**
  - Confirm SW1 (Power) is toggled ON (see physical controls).

---

## 2. Device Sequence Issues
- **Sequence Out of Order:**
  - Press SW1 (Power) to toggle outputs OFF, then ON again to reset.
  - Hold SW1 + SW3 together for 5 seconds to reset to State 1 (outputs off).
  - If the sequence still seems incorrect, re-upload the firmware to the device.
- **Device Stuck in a State:**
  - Try toggling SW1 OFF/ON.
  - Hold SW1 + SW3 for a hard reset.
  - If unresponsive, power cycle the device (disconnect/reconnect battery or USB).
    - This can be done without opening the device by hooking device up to Arduino IDE and re-flashing the current code

---

## 3. Output & Animation Issues
- **No Lights or Effects:**
  - Confirm outputEnabled is ON (see Serial Monitor or LED indicator).
  - Check all physical connections to LEDs, servos, and NeoPixels.
  - Ensure the Prop-Maker FeatherWing is seated properly.
- **Servos Not Moving:**
  - Check servo power and signal wiring.
  - Ensure the PCA9685 servo wing is connected and powered.
  - Try swapping servos to rule out a faulty unit.
- **NeoPixels Not Lighting:**
  - Confirm correct data pin and ground connection.
  - Check that 5V battery is charged and plugged in.
  - Try a known-good NeoPixel strip.

---

## 4. Common Error Scenarios
- **Device Not Responding to Switches:** ~These are tasks for Device Team~
  - Check switch wiring and solder joints.
  - Test switches with a multimeter for continuity.
- **Random or Unstable Behavior:**
  - Check for loose wires or shorts.
  - Ensure all grounds are connected.
  - Try running from USB power only (remove battery) to rule out power noise.
- **Serial Monitor Not Showing Output:**
  - Confirm USB cable is data-capable (not charge-only).
  - Set baud rate to 115200 in Serial Monitor.
  - Ensure the correct COM port is selected.

---

## 5. Firmware & Software Checks
- **Re-upload Firmware:**
  - Use Arduino IDE or PlatformIO to upload the latest code.
  - Confirm successful upload (watch for errors in the IDE).
- **Check DeviceConfig.h:**
  - Verify pin assignments and tuning parameters match your hardware.
- **Library Dependencies:**
  - Ensure all required libraries are installed (see README or Arduino/libraries/).

---

## 6. Additional Tips
- **Document Observations:**
  - Note LED colors, servo movement, and sequence timing for troubleshooting.
- **Test One Subsystem at a Time:**
  - Disconnect servos, LEDs, or NeoPixels to isolate issues.
- **Consult the Serial Monitor:**
  - Add Serial.println() statements for additional debugging info.

---

## 7. Getting Help
- **Check README.md and TROUBLESHOOTING.md for updates.**
- **Contact Eben Alguire or Emery Smith.**
    - Please provide them with a detailed discription of the issue and what has been done so far

---

**See also:**
- arduino/Orciny_Device/Orciny_Device_Animation_Timeline.md
- arduino/Orciny_Device/DeviceConfig.h
- arduino/TROUBLESHOOTING.md

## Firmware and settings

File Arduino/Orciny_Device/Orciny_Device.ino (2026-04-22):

#include <OrcinyCommon.h>
#include <ColorPalettes.h>
#include <AnimationPalettes.h>

// =============================================================================
// Orciny_Device.ino
// Version : V 0.9.0
// Orciny Device — FX Controller Main Program
// Board: Adafruit Feather RP2040
// Wings: Prop-Maker FeatherWing, 8-Channel Servo FeatherWing (PCA9685)
//
// USAGE INSTRUCTIONS:
//   1. Review and adjust DeviceConfig.h for pin assignments and tuning.
//   2. See "STATE BEHAVIORS" for effect logic (doStateX functions).
//   3. Upload and test. Use the three physical switches to cycle states.
//
// PHYSICAL CONTROLS:
//   SW1 (GP27): Toggle all outputs on/off
//   SW2 (GP28): Step backward through states
//   SW3 (GP29): Step forward through states
//   SW1 + SW3 held 5s: Reset to State 1, outputs off
//
// USB SERIAL (115200 baud):
//   Prints state changes. Add Serial.println() for debugging.
//
// OUTPUTS OVERVIEW:
//   Spark channels   — GP18 / GP19 / GP20 / GP24 (analogWrite, 0–255)
//   Beam LED Red     — GP11 (analogWrite, 0–255)
//   Beam LED Green   — GP12 (analogWrite, 0–255)
//   Beam LED Blue    — GP13 (analogWrite, 0–255)
//   Pump MOSFET      — GP1 (PUMP_PIN, digitalWrite/analogWrite, PWM capable)
//   Pulse Filament   — GP0 (PULSE_FILAMENT_PIN, analogWrite, PWM fading)
//   Servo A (claw)   — PCA9685 channel 0 (setServo(0, angle 22–120))
//   Servo B (claw)   — PCA9685 channel 1 (setServo(1, angle 22–120))
//   NeoPixel strip   — GP25 (166 pixels, use neoPixelSetAll())
// =============================================================================

// Core libraries
#include <Wire.h>                      // I2C bus (required for servo driver)
#include <Adafruit_PWMServoDriver.h>   // PCA9685 servo wing library
#include <Adafruit_NeoPixel.h>         // NeoPixel strip library
#include "DeviceConfig.h"              // Centralized pin and parameter definitions
#include <OrcinyEffects_PumpPulse.h>

// --- Global static variables for state tracking (resettable) ---
uint32_t doStateInactive_nextSparkMs = 0;
uint32_t doStateBootUp_stateEnteredMs  = 0;
uint32_t doStateBootUp_nextSparkMs     = 0;
uint32_t doStateBootUp_nextChaseMs     = 0;
uint32_t doStateBootUp_nextServoMs     = 0;
bool     doStateBootUp_pincersRigid    = false;
bool     doStateBootUp_servo1Active    = false;
bool     doStateBootUp_servoLimp       = false;
int8_t   doStateBootUp_servoDir        = 1;
uint8_t  doStateBootUp_servoAngle      = 22;
bool     doStateBootUp_cyanPulsePhase  = true;
uint32_t doStateFailure_stateEnteredMs = 0;
uint32_t doStateFailure_nextSparkMs    = 0;
uint32_t doStateFailure_nextServoMs    = 0;

// =============================================================================
// STEP 1 — PIN CONFIGURATION & TUNING PARAMETERS
// All pin and parameter definitions are now in DeviceConfig.h
// Only change these if you are building on different hardware.
// =============================================================================
// STEP 2 - COLOR PALETTE DESIGNATORS
// Use these enums to select named color palettes for beam and NeoPixels.
// To add more, be sure to create a name  in the ID field and add the corresponding RGB(W) values in the BEAM_PALETTES and NEO_PALETTES arrays below.
// =============================================================================

enum BeamPaletteId : uint8_t {
  BEAM_PALETTE_OFF = 0,
  BEAM_PALETTE_COOL,
  BEAM_PALETTE_EMBER,
  BEAM_PALETTE_CYAN,
  BEAM_PALETTE_VIOLET,
  BEAM_PALETTE_MAGENTA,
  BEAM_PALETTE_GOLDEN,
  BEAM_PALETTE_TEAL,
  BEAM_PALETTE_WHITE,
};

enum NeoPaletteId : uint8_t {
  NEO_PALETTE_OFF = 0,
  NEO_PALETTE_WARM_WHITE,
  NEO_PALETTE_EMBER,
  NEO_PALETTE_CYAN,
  NEO_PALETTE_VIOLET,
  NEO_PALETTE_MAGENTA,
  NEO_PALETTE_GOLDEN,
  NEO_PALETTE_TEAL,
  NEO_PALETTE_WHITE,
};

struct BeamPaletteColor {
  uint8_t red;
  uint8_t green;
  uint8_t blue;
};


struct NeoPaletteColor {
  uint8_t red;
  uint8_t green;
  uint8_t blue;
};

const BeamPaletteColor BEAM_PALETTES[] = {
  {0,   0,   0},    // OFF
  {120, 210, 255},  // COOL
  {255, 95,  18},   // EMBER
  {0,   220, 255},  // CYAN
  {175, 70,  255},  // VIOLET
  {255, 0,   200},  // MAGENTA
  {255, 180, 30},   // GOLDEN
  {40,  220, 200},  // TEAL
  {255, 255, 255},  // WHITE
};

const NeoPaletteColor NEO_PALETTES[] = {
  {0,   0,   0},    // OFF
  {140, 130, 110},  // WARM_WHITE (approximation)
  {220, 70,  8},    // EMBER
  {0,   180, 230},  // CYAN
  {140, 45,  210},  // VIOLET
  {255, 0,   180},  // MAGENTA
  {255, 180, 0},    // GOLDEN
  {0,   200, 180},  // TEAL
  {200, 200, 200},  // WHITE
};

// =============================================================================
// STEP 3 - STATE PALETTE SELECTORS
// One-line per-state color selectors.  Change these values to retheme states
// without editing state logic code.
// =============================================================================

// Per-state palette selectors — edit these to retheme without touching state logic.
// Sequences now match the CSV sequence map.
const BeamPaletteId STATE_INACTIVE_BEAM_PALETTE = BEAM_PALETTE_OFF;
const BeamPaletteId STATE_BOOT_BEAM_PALETTE     = BEAM_PALETTE_GOLDEN;
const BeamPaletteId STATE_DEMO_BEAM_PALETTE     = BEAM_PALETTE_CYAN;
const BeamPaletteId STATE_FAILURE_BEAM_PALETTE  = BEAM_PALETTE_WHITE;

const NeoPaletteId STATE_INACTIVE_NEO_PALETTE   = NEO_PALETTE_OFF;
const NeoPaletteId STATE_BOOT_NEO_PALETTE       = NEO_PALETTE_CYAN;
const NeoPaletteId STATE_DEMO_NEO_PALETTE       = NEO_PALETTE_CYAN;
const NeoPaletteId STATE_FAILURE_NEO_PALETTE    = NEO_PALETTE_WHITE;

// =============================================================================
// STEP 4 — STATE DEFINITIONS
// Add or remove states here.  Update STATE_COUNT to match.
// The state names show up in Serial Monitor output.
// =============================================================================

enum DeviceState : uint8_t {
  STATE_OFF      = 0,  // Outputs disabled — safe idle
  STATE_INACTIVE,      // Sequence 0: Inactive
  STATE_BOOT,          // Sequence 1: Boot up
  STATE_DEMO,          // Sequence 2: Demonstrate
  STATE_FAILURE,       // Sequence 3: Device Failure
  STATE_COUNT          // Keep this last — used to wrap the selector
};

// Readable names printed to Serial Monitor when states change.
const char* STATE_NAMES[] = { "OFF", "Inactive", "Boot Up", "Demonstrate", "Device Failure" };

// =============================================================================
// STEP 5 — GLOBAL OBJECTS (nothing to change here in most cases)
// =============================================================================

Adafruit_PWMServoDriver servoDriver(SERVO_I2C_ADDR);
Adafruit_NeoPixel       strip(NEO_PIXEL_COUNT, NEO_DATA_PIN, NEO_COLOR_ORDER + NEO_KHZ800);

DeviceState currentState   = STATE_INACTIVE;   // Which state is active
bool        outputEnabled  = false;     // Master on/off flag

// Internal switch state tracking (one struct per button).
struct SwitchState {
  uint8_t  pin;
  bool     stable;       // Last confirmed stable reading
  bool     raw;          // Most recent raw reading
  bool     pressed;      // Single-shot: true for one loop on press
  bool     released;     // Single-shot: true for one loop on release
  uint32_t lastChangeMs;
};

SwitchState swPower = { SW_POWER_PIN };
SwitchState swPlayPause  = { SW_PREV_PIN  }; // SW2: Play/Pause button
SwitchState swBack  = { SW_NEXT_PIN  };      // SW3: Immediate Failure button

// Pause/play state
bool isPaused = false;
DeviceState pausedState = STATE_INACTIVE;

// Reset chord tracking
uint32_t resetStartMs       = 0;
bool     resetFired         = false;
bool     suppressPowerEvent = false;
bool     suppressNextEvent  = false;

// Helper to reset all static variables in state functions
void resetStateStatics() {
  // doStateInactive static
  doStateInactive_nextSparkMs = 0;

  // doStateBootUp statics
  doStateBootUp_stateEnteredMs = 0;
  doStateBootUp_nextSparkMs = 0;
  doStateBootUp_nextChaseMs = 0;
  doStateBootUp_nextServoMs = 0;
  doStateBootUp_pincersRigid = false;
  doStateBootUp_servo1Active = false;
  doStateBootUp_servoLimp = false;
  doStateBootUp_servoDir = 1;
  doStateBootUp_servoAngle = 22;
  doStateBootUp_cyanPulsePhase = true;

  // doStateFailure statics
  doStateFailure_stateEnteredMs = 0;
  doStateFailure_nextSparkMs = 0;
  doStateFailure_nextServoMs = 0;
}

// =============================================================================
// HELPER FUNCTIONS — forward declarations
// These are implemented at the bottom of the file.
// =============================================================================

void updateSwitch(SwitchState &sw, uint32_t now);
void handleSwitches(uint32_t now);
void printState();
void setServo(uint8_t channel, uint8_t angle);
void setBeamPalette(BeamPaletteId paletteId, uint8_t level = 255);
void setNeoPalette(NeoPaletteId paletteId, uint8_t level = 255);
void neoPixelSetAll(uint8_t r, uint8_t g, uint8_t b, uint8_t w = 0);
void neoPixelOff();
void allOutputsOff();
void neoChase(uint8_t r, uint8_t g, uint8_t b, uint8_t len, uint32_t intervalMs);
void servoIdle(uint8_t channel);

// =============================================================================
// STATE BEHAVIORS
// Each doStateX() function is called every loop iteration while that state
// is active and outputEnabled is true.
//
// IMPORTANT: Do NOT use delay() inside these functions.  Use millis() for
//            timing.  See the non-blocking timer example in State 1 below.
// =============================================================================

// --- STATE: INACTIVE (Sequence 0) -------------------------------------------
// Sparse random single sparks with 3–5 second gaps. Beam and NeoPixels off.

void doStateInactive() {
  static uint32_t &nextSparkMs = doStateInactive_nextSparkMs;
  uint32_t now = millis();

  if (now >= nextSparkMs) {
    // Pick a random spark channel
    const uint8_t pins[] = {SPARK_PIN_1, SPARK_PIN_2, SPARK_PIN_3, SPARK_PIN_4};
    uint8_t ch = pins[random(0, 4)];
    analogWrite(ch, random(140, 220));
    delay(20);
    analogWrite(ch, 0);
    nextSparkMs = now + random(3000, 5000);
  }

  // Beam and NeoPixels stay off in idle
  analogWrite(BEAM_RED_PIN, 0);
  analogWrite(BEAM_GREEN_PIN, 0);
  analogWrite(BEAM_BLUE_PIN, 0);
  neoPixelOff();
}

// --- STATE: BOOT UP (Sequence 1) ---------------------------------------------
// Timeline (approximate):
//   0–4s    : Sparse sparks; cyan chases, slow to fast
//   4–14s   : Sparks continue; cyan chases ramp up
//   14–22s  : Orange chases begin; pincers go rigid
//   22–24s  : Core pulses cyan/orange; beam fades to golden
//   24–26s  : Servo 1 oscillates
//   26–32s  : Both servos limp
//   32s+    : Transition to Demonstrate state
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
void loop() {
  const uint32_t now = millis();

  // Read and debounce all three switches; update outputEnabled and currentState.
  handleSwitches(now);

  if (!outputEnabled) {
    // Master off — ensure everything is dark.
    allOutputsOff();
    return;
  }

  // If paused, do not advance state logic
  if (isPaused) {
    // Optionally, keep outputs as they were
    return;
  }

  // Dispatch to the active state's behavior function.
  switch (currentState) {
    case STATE_INACTIVE: doStateInactive(); break;
    case STATE_BOOT:     doStateBootUp();   break;
    case STATE_DEMO:     doStateDemo();     break;
    case STATE_FAILURE:  doStateFailure();  break;
    default:             allOutputsOff();   break;
  }

  // Push NeoPixel changes to the strip once per loop.
  strip.show();
}

// =============================================================================
// HELPER IMPLEMENTATIONS
// =============================================================================

// Set a servo to the specified angle (0–180°) on the given PCA9685 channel.
void setServo(uint8_t channel, uint8_t angle) {
  uint16_t pulse = map(angle, 0, 180, SERVO_PULSE_MIN, SERVO_PULSE_MAX);
  servoDriver.setPWM(channel, 0, pulse);
}

// Apply a named RGB beam palette at a 0–255 brightness level.
void setBeamPalette(BeamPaletteId paletteId, uint8_t level) {
  const uint8_t index = static_cast<uint8_t>(paletteId);
  if (index >= (sizeof(BEAM_PALETTES) / sizeof(BEAM_PALETTES[0]))) {
    return;
  }

  const BeamPaletteColor &palette = BEAM_PALETTES[index];
  analogWrite(BEAM_RED_PIN,   (palette.red   * level) / 255);
  analogWrite(BEAM_GREEN_PIN, (palette.green * level) / 255);
  analogWrite(BEAM_BLUE_PIN,  (palette.blue  * level) / 255);
}

// Apply a named RGB NeoPixel palette at a 0–255 brightness level.
void setNeoPalette(NeoPaletteId paletteId, uint8_t level) {
  const uint8_t index = static_cast<uint8_t>(paletteId);
  if (index >= (sizeof(NEO_PALETTES) / sizeof(NEO_PALETTES[0]))) {
    return;
  }

  const NeoPaletteColor &palette = NEO_PALETTES[index];
  neoPixelSetAll((palette.red   * level) / 255,
                 (palette.green * level) / 255,
                 (palette.blue  * level) / 255);
}

// Set every NeoPixel to the same RGBW color.
// w (white channel) defaults to 0 if not provided (RGBW strips only).
void neoPixelSetAll(uint8_t r, uint8_t g, uint8_t b, uint8_t w) {
  for (int i = 0; i < strip.numPixels(); i++) {
    strip.setPixelColor(i, strip.Color(r, g, b, w));
  }
  // Caller must call strip.show() to push the update — or rely on loop().
}

// Animate a short run of pixels from pixel 0 toward the end of the strip.
// r/g/b: chase color; len: length of the lit run; stepMs: ms per pixel advance.
// Non-blocking: advances one step per call if stepMs has elapsed.
void neoChase(uint8_t r, uint8_t g, uint8_t b, uint8_t len, uint32_t stepMs) {
  static uint16_t head   = 0;
  static uint32_t nextMs = 0;
  uint32_t now = millis();
  if (now < nextMs) return;
  for (int i = 0; i < strip.numPixels(); i++) {
    strip.setPixelColor(i, 0);
  }
  // Main chase body: fade from head (brightest) to tail (dimmest)
  for (int i = 0; i < len; i++) {
    int px = head - i;
    if (px >= 0 && px < strip.numPixels()) {
      uint8_t fade = map(i, 0, len, 255, 30);
      strip.setPixelColor(px, strip.Color((r * fade) / 255,
                                          (g * fade) / 255,
                                          (b * fade) / 255, 0));
    }
  }
  // Fade-in: 3 pixels before the head (ascending brightness)
  for (int j = 1; j <= 3; j++) {
    int px = head + j;
    if (px >= 0 && px < strip.numPixels()) {
      uint8_t fade = map(j, 3, 0, 30, 255); // 3: dimmest, 1: brightest
      strip.setPixelColor(px, strip.Color((r * fade) / 255,
                                          (g * fade) / 255,
                                          (b * fade) / 255, 0));
    }
  }
  // Fade-out: 3 pixels after the tail (descending brightness)
  for (int j = 1; j <= 3; j++) {
    int px = head - len - j + 1;
    if (px >= 0 && px < strip.numPixels()) {
      uint8_t fade = map(j, 1, 3, 30, 0); // 1: dimmest, 3: off
      strip.setPixelColor(px, strip.Color((r * fade) / 255,
                                          (g * fade) / 255,
                                          (b * fade) / 255, 0));
    }
  }
  strip.show();
  head   = (head + 1) % strip.numPixels();
  nextMs = now + stepMs;
}

// Turn all NeoPixels off immediately.
void neoPixelOff() {
  strip.clear();
  strip.show();
}

// Shut down all output subsystems (beam, sparks, servos, NeoPixels).
void allOutputsOff() {
  analogWrite(BEAM_RED_PIN,   0);
  analogWrite(BEAM_GREEN_PIN, 0);
  analogWrite(BEAM_BLUE_PIN,  0);
  analogWrite(SPARK_PIN_1, 0);
  analogWrite(SPARK_PIN_2, 0);
  analogWrite(SPARK_PIN_3, 0);
  analogWrite(SPARK_PIN_4, 0);
  servoIdle(0);
  servoIdle(1);
  neoPixelOff();
}

// Stop driving a servo (removes PWM signal so servo goes limp).
void servoIdle(uint8_t channel) {
  servoDriver.setPWM(channel, 0, 0);
}

// Print current output and state to Serial Monitor.
void printState() {
  Serial.print(F("Output: "));
  Serial.print(outputEnabled ? F("ON") : F("OFF"));
  Serial.print(F("  |  State: "));
  Serial.println(STATE_NAMES[currentState]);
}

// Debounce one switch. Call every loop with the current millis() value.
// Populates sw.pressed and sw.released as single-shot flags.
void updateSwitch(SwitchState &sw, uint32_t now) {
  sw.pressed  = false;
  sw.released = false;

  const bool sampled = (digitalRead(sw.pin) == LOW);

  if (sampled != sw.raw) {
    sw.raw          = sampled;
    sw.lastChangeMs = now;
  }

  if ((now - sw.lastChangeMs) < DEBOUNCE_MS) {
    return;  // Still bouncing — wait
  }

  if (sw.stable == sw.raw) {
    return;  // No change
  }

  sw.stable = sw.raw;

  if (sw.stable) {
    sw.pressed  = true;
  } else {
    sw.released = true;
  }
}

// Process all three switches and update outputEnabled and currentState.
void handleSwitches(uint32_t now) {
  updateSwitch(swPower, now);
  updateSwitch(swPlayPause,  now);
  // Increase debounce for SW3 (Back/Immediate Failure)
  static uint32_t lastBackReleaseMs = 0;
  updateSwitch(swBack,  now);

  // --- Reset chord: SW1 + SW3 held together for RESET_HOLD_MS ---------------
  const bool chordDown = swPower.stable && swBack.stable;

  if (chordDown) {
    if (resetStartMs == 0) {
      resetStartMs       = now;
      suppressPowerEvent = true;  // Block the toggle event on release
      suppressNextEvent  = true;  // Block the sequence advance on release
    }
    if (!resetFired && (now - resetStartMs >= RESET_HOLD_MS)) {
      resetFired    = true;
      outputEnabled = false;
      currentState  = STATE_INACTIVE;
      allOutputsOff();
      Serial.println(F("RESET"));
      printState();
    }
  } else if (!swPower.stable && !swBack.stable) {
    // Both buttons fully released — clear chord tracking.
    resetStartMs       = 0;
    resetFired         = false;
    suppressPowerEvent = false;
    suppressNextEvent  = false;
  }

  // --- SW3 (Back): immediate Device Failure ---
  // Only allow after both reset buttons have been released following a reset chord
  static bool allowFailureAfterReset = true;
  if (resetFired) {
    allowFailureAfterReset = false;
  }
  if (!swPower.stable && !swBack.stable) {
    // Both released, safe to allow failure again
    allowFailureAfterReset = true;
    resetFired = false;
  }
  if (swBack.released && allowFailureAfterReset) {
    // Debounce: ignore if released too soon after reset or previous press
    if (now - lastBackReleaseMs > 400) { // 400ms debounce for failure
      isPaused = false;
      currentState = STATE_FAILURE;
      printState();
      lastBackReleaseMs = now;
    }
  }

  // --- SW1: toggle output on/off --------------------------------------------
  if (swPower.released && !suppressPowerEvent) {
    outputEnabled = !outputEnabled;
    if (!outputEnabled) {
      allOutputsOff();
    }
    printState();
  }

  // --- SW2 (Play/Pause): Pause/Play logic ---
  if (swPlayPause.released && !suppressNextEvent) {
    if (isPaused) {
      // Resume from pause
      isPaused = false;
      currentState = pausedState;
      printState();
    } else {
      if (currentState == STATE_INACTIVE) {
        // Start sequence from Inactive
        currentState = STATE_BOOT;
        printState();
      } else if (currentState == STATE_BOOT || currentState == STATE_DEMO) {
        // Pause in place
        isPaused = true;
        pausedState = currentState;
        printState();
      }
      // If in FAILURE, do nothing
    }
  }

 }

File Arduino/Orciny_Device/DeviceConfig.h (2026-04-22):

// =============================================================================
// DeviceConfig.h
// Version : V 0.9.0
// Centralized pin and parameter definitions for Orciny Device
// =============================================================================
#ifndef ORCINY_DEVICE_CONFIG_H
#define ORCINY_DEVICE_CONFIG_H

// Pin assignments (update only if hardware changes)
#define PULSE_FILAMENT_PIN   0   // PWM capable (fading effect)
#define PUMP_PIN             1   // PWM/digital (MOSFET)
#define PROP_MAKER_PWR_PIN   10  // Must be HIGH for MOSFETs to work
#define BEAM_RED_PIN         11  // PWM
#define BEAM_GREEN_PIN       12  // PWM
#define BEAM_BLUE_PIN        13  // PWM
#define SPARK_PIN_1          18  // PWM
#define SPARK_PIN_2          19  // PWM
#define SPARK_PIN_3          20  // PWM
#define SPARK_PIN_4          24  // PWM
#define NEO_DATA_PIN         25  // NeoPixel strip
#define NEO_PIXEL_COUNT      166 // Number of NeoPixels
#define NEO_COLOR_ORDER      NEO_GRB
#define SW_POWER_PIN         27  // SW1
#define SW_PREV_PIN          28  // SW2
#define SW_NEXT_PIN          29  // SW3

// Tuning parameters
#define DEBOUNCE_MS          40    // ms debounce for switches
#define RESET_HOLD_MS        5000  // ms to hold SW1+SW3 for reset
#define SERVO_I2C_ADDR       0x40  // PCA9685 I2C address
#define SERVO_PULSE_MIN      120   // Servo min pulse (0 deg)
#define SERVO_PULSE_MAX      600   // Servo max pulse (180 deg)

#endif // ORCINY_DEVICE_CONFIG_H

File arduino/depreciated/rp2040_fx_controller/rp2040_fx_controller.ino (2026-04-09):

#include <Adafruit_PWMServoDriver.h>
#include <Wire.h>

#include <OrcinyCommon.h>

#include "DeviceConfig.h"

using orciny::CoreFrame;
using orciny::EffectCommand;
using orciny::CoreMode;

enum SequenceId : uint8_t {
  SEQUENCE_1 = 0,
  SEQUENCE_2,
  SEQUENCE_3,
  SEQUENCE_COUNT,
};

struct SceneProfile {
  bool sparksEnabled;
  uint8_t sparksIntensity;
  bool beamEnabled;
  bool clawEnabled;
  CoreFrame coreFrame;
};

class MomentarySwitch {
 public:
  void begin(uint8_t pin) {
    pin_ = pin;
    pinMode(pin_, INPUT_PULLUP);
    const bool initialPressed = (digitalRead(pin_) == LOW);
    stablePressed_ = initialPressed;
    rawPressed_ = initialPressed;
    lastChangeMs_ = millis();
  }

  void update(uint32_t now) {
    pressedEvent_ = false;
    releasedEvent_ = false;

    const bool sampledPressed = (digitalRead(pin_) == LOW);
    if (sampledPressed != rawPressed_) {
      rawPressed_ = sampledPressed;
      lastChangeMs_ = now;
    }

    if ((now - lastChangeMs_) < device_config::kSwitchDebounceMs) {
      return;
    }

    if (stablePressed_ == rawPressed_) {
      return;
    }

    stablePressed_ = rawPressed_;
    if (stablePressed_) {
      pressedEvent_ = true;
    } else {
      releasedEvent_ = true;
    }
  }

  bool isPressed() const { return stablePressed_; }
  bool wasPressed() const { return pressedEvent_; }
  bool wasReleased() const { return releasedEvent_; }

 private:
  uint8_t pin_ = 0;
  bool stablePressed_ = false;
  bool rawPressed_ = false;
  bool pressedEvent_ = false;
  bool releasedEvent_ = false;
  uint32_t lastChangeMs_ = 0;
};

class SparkChannel {
 public:
  void begin(uint8_t pin) {
    pin_ = pin;
    pinMode(pin_, OUTPUT);
    analogWrite(pin_, 0);
    nextEventMs_ = millis() + random(30, 180);
  }

  void update(uint32_t now, bool enabled, uint8_t intensity) {
    if (!enabled) {
      analogWrite(pin_, 0);
      active_ = false;
      nextEventMs_ = now + random(80, 200);
      return;
    }

    if (active_) {
      if (now >= flashUntilMs_) {
        active_ = false;
        analogWrite(pin_, 0);
        nextEventMs_ = now + random(25, 140);
      }
      return;
    }

    if (now < nextEventMs_) {
      return;
    }

    const int minimum = max(32, intensity / 3);
    const int peak = max(minimum + 1, static_cast<int>(intensity) + 1);
    analogWrite(pin_, random(minimum, peak));
    flashUntilMs_ = now + random(15, 70);
    active_ = true;
  }

 private:
  uint8_t pin_ = 0;
  bool active_ = false;
  uint32_t nextEventMs_ = 0;
  uint32_t flashUntilMs_ = 0;
};

class BeamEffect {
 public:
  void begin(uint8_t led1Pin, uint8_t led2Pin, uint8_t led3Pin) {
    redPin_ = led1Pin;
    greenPin_ = led2Pin;
    bluePin_ = led3Pin;
    pinMode(redPin_, OUTPUT);
    pinMode(greenPin_, OUTPUT);
    pinMode(bluePin_, OUTPUT);
    stop();
  }

  void update(uint32_t now, bool enabled) {
    if (!enabled) {
      stop();
      return;
    }

    const uint16_t phase = now % 2400;
    const uint8_t swell = phase < 1200 ? map(phase, 0, 1200, 100, 255)
                                       : map(phase, 1200, 2400, 255, 100);
    analogWrite(redPin_, swell / 5);
    analogWrite(greenPin_, swell);
    analogWrite(bluePin_, min<uint16_t>(255, swell + 30));
    active_ = true;
  }

  void stop() {
    analogWrite(redPin_, 0);
    analogWrite(greenPin_, 0);
    analogWrite(bluePin_, 0);
    active_ = false;
  }

 private:
  uint8_t redPin_ = 0;
  uint8_t greenPin_ = 0;
  uint8_t bluePin_ = 0;
  bool active_ = false;
};

class ClawEffect {
 public:
  void begin(Adafruit_PWMServoDriver &driver,
             uint8_t servoChannelA,
             uint8_t servoChannelB,
             uint8_t minAngleA,
             uint8_t maxAngleA,
             uint8_t minAngleB,
             uint8_t maxAngleB) {
    driver_ = &driver;
    servoChannelA_ = servoChannelA;
    servoChannelB_ = servoChannelB;
    minAngleA_ = min(minAngleA, maxAngleA);
    maxAngleA_ = max(minAngleA, maxAngleA);
    minAngleB_ = min(minAngleB, maxAngleB);
    maxAngleB_ = max(minAngleB, maxAngleB);
    angle_ = minAngleA_;
    direction_ = 1;
    writeServos(static_cast<uint8_t>(angle_));
  }

  void update(uint32_t now, bool enabled) {
    if (!enabled) {
      stop();
      return;
    }

    if (now < nextStepMs_) {
      return;
    }

    angle_ += direction_;
    if (angle_ >= maxAngleA_) {
      angle_ = maxAngleA_;
      direction_ = -1;
    } else if (angle_ <= minAngleA_) {
      angle_ = minAngleA_;
      direction_ = 1;
    }

    writeServos(static_cast<uint8_t>(angle_));
    nextStepMs_ = now + device_config::kClawStepIntervalMs;
    active_ = true;
  }

  void stop() {
    if (!active_) {
      return;
    }
    writeServos(minAngleA_);
    active_ = false;
  }

 private:
  uint16_t angleToPulse(uint8_t angle) const {
    return map(angle,
               0,
               180,
               device_config::kServoMinPulse,
               device_config::kServoMaxPulse);
  }

  uint8_t mapAngleForB(uint8_t angleA) const {
    return map(angleA, minAngleA_, maxAngleA_, maxAngleB_, minAngleB_);
  }

  void writeServos(uint8_t angleA) {
    if (driver_ == nullptr) {
      return;
    }

    const uint8_t clampedA = constrain(angleA, minAngleA_, maxAngleA_);
    const uint8_t angleB = constrain(mapAngleForB(clampedA), minAngleB_, maxAngleB_);
    driver_->setPWM(servoChannelA_, 0, angleToPulse(clampedA));
    driver_->setPWM(servoChannelB_, 0, angleToPulse(angleB));
  }

  Adafruit_PWMServoDriver *driver_ = nullptr;
  uint8_t servoChannelA_ = 0;
  uint8_t servoChannelB_ = 1;
  int16_t angle_ = 0;
  uint8_t minAngleA_ = 0;
  uint8_t maxAngleA_ = 180;
  uint8_t minAngleB_ = 0;
  uint8_t maxAngleB_ = 180;
  int8_t direction_ = 1;
  bool active_ = false;
  uint32_t nextStepMs_ = 0;
};

SparkChannel sparks[device_config::kSparkCount];
BeamEffect beamEffect;
ClawEffect clawEffect;
Adafruit_PWMServoDriver servoDriver(device_config::kServoDriverI2cAddress);

MomentarySwitch powerSwitch;
MomentarySwitch previousSwitch;
MomentarySwitch nextSwitch;

SequenceId currentSequence = SEQUENCE_1;
bool outputEnabled = false;
String usbCommandBuffer;
String effectLinkBuffer;
uint32_t lastCoreFrameMs = 0;
uint32_t lastEffectCommandMs = 0;
uint32_t resetChordStartMs = 0;
bool resetChordTriggered = false;
bool suppressPowerRelease = false;
bool suppressNextRelease = false;
uint32_t peltierHoldUntilMs = 0;
EffectCommand currentEffectCommand = orciny::defaultEffectCommand();

void printHelp() {
  Serial.println(F("Commands: help, on, off, toggle, prev, next, seq1, seq2, seq3, reset"));
}

void printSequenceStatus() {
  Serial.print(F("Power -> "));
  Serial.print(outputEnabled ? F("ON") : F("OFF"));
  Serial.print(F(", Sequence -> "));
  Serial.println(static_cast<uint8_t>(currentSequence) + 1);
}
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

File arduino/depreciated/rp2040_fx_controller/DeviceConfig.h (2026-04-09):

#pragma once

#include <Arduino.h>

namespace device_config {

static constexpr uint32_t kUsbBaudRate = 115200;
static constexpr uint32_t kCoreLinkBaudRate = 115200;
static constexpr uint32_t kCoreLinkPeriodMs = 40;
static constexpr uint16_t kSwitchDebounceMs = 30;
static constexpr uint32_t kResetHoldMs = 5000;
static constexpr uint8_t kServoDriverI2cAddress = 0x40;

static constexpr uint8_t kSparkCount = 4;
// Feather RP2040 breakout-safe spark pins:
// SP1=GP7 (D5), SP2=GP6 (D4), SP3=GP9 (D9), SP4=GP24 (D24)
static constexpr uint8_t kSparkPins[kSparkCount] = {7, 6, 9, 24};
// GP8 is currently assigned to peltier control in this revision.
// static constexpr uint8_t kPumpControlPin = 8;

static constexpr uint8_t kPowerSwitchPin = A1;    // GP27
static constexpr uint8_t kPreviousSwitchPin = A2;  // GP28
static constexpr uint8_t kNextSwitchPin = A3;      // GP29

// Prop-Maker FeatherWing MOSFET LED outputs for high-power lighting.
// GP10 (D10) is the Prop-Maker PWR enable pin and must be held high.
// Beam LED is common anode RGB: LED1=Red(Q6), LED2=Green(Q7), LED3=Blue(Q8)
// H-BEAM-PWR connector: pin2(red wire)=R, pin4(green wire)=G, pin3(blue wire)=B
static constexpr uint8_t kPropMakerPwrPin = 10;
static constexpr uint8_t kPropMakerLed1Pin = 11;  // Red channel
static constexpr uint8_t kPropMakerLed2Pin = 12;  // Green channel
static constexpr uint8_t kPropMakerLed3Pin = 13;  // Blue channel

// Peltier load control MOSFET gate (Q9).
// Keep enabled briefly after beam turns off to dissipate residual heat.
static constexpr uint8_t kPeltierControlPin = 8;
static constexpr uint16_t kPeltierPostBeamHoldMs = 12000;

// 8-channel Servo FeatherWing (PCA9685) channels/pulse timing.
static constexpr uint8_t kServoChannelA = 0;
static constexpr uint8_t kServoChannelB = 1;
static constexpr uint16_t kServoMinPulse = 120;
static constexpr uint16_t kServoMaxPulse = 600;
static constexpr uint8_t kServoAMinAngle = 22;
static constexpr uint8_t kServoAMaxAngle = 120;
static constexpr uint8_t kServoBMinAngle = 22;
static constexpr uint8_t kServoBMaxAngle = 120;
static constexpr uint16_t kClawStepIntervalMs = 8;
static constexpr uint16_t kEffectCommandTimeoutMs = 400;

}  // namespace device_config

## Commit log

2026-03-30 Initial Orciny device firmware and circuit docs
    [fritzing_wire_labels.csv, orciny_wiring_starter.fzz]
2026-03-31 Refactor controller roles and update power/resistor schematics
    [fritzing_wire_labels.csv, sheet_beam_peltier.kicad_sch, sheet_filaments.kicad_sch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]
2026-03-31 Wire series resistors and fuse branches explicitly
    [sheet_beam_peltier.kicad_sch, sheet_filaments.kicad_sch, sheet_power.kicad_sch]
2026-03-31 Assign standard SMD footprints to resistors and fuses
    [sheet_beam_peltier.kicad_sch, sheet_filaments.kicad_sch, sheet_power.kicad_sch]
2026-03-31 Migrate Orciny device to single-strip core and GPIO pump control
    Replace the M0 NeoPXL8-based core controller with a single 30-pixel NeoPixel strip on D13 and keep Serial1 TX dedicated to RP2040 effect commands.
    Replace Motor FeatherWing pump control with direct RP2040 GP8 MOSFET drive while keeping GP7 assigned to the FP-S14B claw servo.
    Update both firmware sketches and DeviceConfig headers to match the revised controller responsibilities, serial command flow, and output mappings.
    Restructure the KiCad project by removing the legacy NeoPXL8 and motor-and-claw sheets, adding the new core-strip and pump-and-claw sheets, and aligning the block hierarchy and power sheet with the current 5V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
    [fritzing_wire_labels.csv, orciny_blocks.kicad_sch, orciny_bom.csv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]
2026-03-31 Clean up remaining 5V migration references
    Fix the last stale 12V-oriented wording after the single-strip and GPIO pump migration.
    Update the KiCad netmap grounding note, the Adafruit footprint guide input-jack description, and the BOM peltier sizing note so they all match the committed 5V input and 5V peltier assumptions.
    [orciny_bom.csv]
2026-04-08 Update control hardware mappings and Fusion docs
    [fritzing_wire_labels.csv, orciny_fusion_nets.csv, orciny_fusion_parts.csv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]
2026-04-08 Add Adafruit library mapping for Fusion starter
    [orciny_fusion_adafruit_library_map.csv]
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2026-04-08 Sync KiCad schematics with current hardware
    [orciny_blocks.kicad_sch, sheet_propmaker_led_outputs.kicad_sch, sheet_rp2040_fx.kicad_sch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]
2026-04-08 updated paperwork
    [fritzing_wire_labels.csv, orciny_blocks.kicad_sch, orciny_bom.csv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]
2026-04-08 chore: clean docs and remove legacy design artifacts
    [fritzing_wire_labels.csv, orciny_bom.csv, orciny_fusion_adafruit_library_map.csv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]
2026-04-08 docs: align wiring to RP2040-only power plan and add harness reference
    [orciny_bom.csv]
2026-04-08 Refine harness connector notes and NeoPixel 3.7V capacity guidance
2026-04-08 Alignment pass: fix phantom harness IDs, update Mermaid to RP2040-only, fix BOM NeoPixel pin
    [orciny_bom.csv]
2026-04-08 Document NeoPixel strip bulk capacitor requirement
    [orciny_bom.csv]
2026-04-08 Add NeoPixel bulk capacitor note to harness reference
2026-04-09 Add wire colors and pin assignments; propagate to one-sheet and DeviceConfig
2026-04-09 Correct RP2040 pin mapping for Prop-Maker, spark, and NeoPixel docs
    [orciny_bom.csv]
2026-04-09 Full-sweep cleanup: align README, BOM, netmap, and KiCad hierarchy for RP2040-only design
    [orciny wiring RevB.kicad_sch, orciny_bom.csv]
2026-04-09 Remap peltier control to GP8 and sync firmware/docs
    [orciny_bom.csv]
2026-04-09 Remap spark channels to Feather RP2040 broken-out GPIO pins
    [orciny_bom.csv]
2026-04-10 Reorganize Arduino sketches and add RP2040 starter projects
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2026-04-10 Add servo channel tests and align spark pin map
2026-04-10 Add NeoPixel strip support with animation modes and debug commands
    - Added NeoPixel library include and global strip object (166 pixels, GP4, SK6812)
    - Implemented updateNeoPixel() with all CoreFrame animation modes:
    * EMBER: warm orange random flicker
    * PULSE: smooth color pulse in/out
    * BEAM: beam-linked animation
    * CLAW: trailing tail indicator
    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
2026-04-10 Fix: clamp narrowing conversion errors in sin8 lookup table and initialize NeoPixel data pin LOW on setup
    [rp2040_fx_controller_demo.ino]
2026-04-10 Fix pin conflict: move NeoPixel data to GP25 and sync wiring docs
    [DeviceConfig.h]
2026-04-13 Set effect-link default and add SW1+SW2 standalone switch chord
2026-04-14 Add mode status marker and serial mode switch commands
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2026-04-14 Switch demo to standalone-only mode and clean docs
2026-04-14 Idle claw servos when inactive to reduce power
2026-04-15 V 0.2.0: Add ColorPalettes and AnimationPalettes resources; update sketches to reflect pin/harness changes
2026-04-15 Replace state function examples with palette-based implementations
    - State 1: Ember scene with ColorPalettes::kBeamEmber and kNeoEmber
    - State 2: Pulsing cyan beam with swell modulation using kBeamCyan and kNeoCyan
    - State 3: Full show scene with violet beam, sparks, servo sweep, and cyan NeoPixels
    - Remove hardcoded RGB values in favor of palette references
    - Demonstrate proper palette usage patterns for users
    [rp2040_fx_starter.ino]
2026-04-15 Add OrcinyEffects library with pre-built effect scenes
    - Create OrcinyEffects library at arduino/libraries/OrcinyEffects
    - Implement Scene class with three pre-built effects: Ember, CyanPulse, FullShow
    - Each scene uses ColorPalettes for consistent visuals
    - Add comprehensive library README with usage examples
    - Add OrcinyEffects_Example.ino showing how to integrate library
    - Update main README with getting started guide (beginner vs advanced paths)
    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
2026-04-15 Bump firmware and library versions to 0.2.5
    - Update rp2040_fx_starter and rp2040_fx_controller_demo headers to V 0.2.5
    - Update DeviceConfig.h version to V 0.2.5
    - Update OrcinyCommon and OrcinyEffects headers to V 0.2.5
    - Update OrcinyCommon and OrcinyEffects library.properties to version 0.2.5
    - Update OrcinyEffects example sketch header to V 0.2.5
2026-04-15 Refresh README for current sketch workflows and use-cases
    - Replace getting-started section with explicit sketch use-cases
    - Document starter, demo controller, and hybrid OrcinyEffects paths
    - Update starter guidance to include State 4 AnimationPalettes example
    - Rework usage instructions into path-based workflows
2026-04-15 Fix Arduino library layout and add troubleshooting docs
    [rp2040_fx_starter.ino]
2026-04-15 Fix Arduino switch init loops for compiler compatibility
    [rp2040_fx_starter.ino]
2026-04-15 docs: add RP2040 Boards Manager setup to troubleshooting guide
    Agent-Logs-Url: https://github.com/EbenAET/Orciny-Device/sessions/f7c25338-5a1f-4aee-b69a-892cd6fa46a6
2026-04-15 docs: add v1.0.0 sketchbook migration note in Arduino setup guide
    Agent-Logs-Url: https://github.com/EbenAET/Orciny-Device/sessions/a8151396-370e-429a-91f2-8fb356fa3971
2026-04-19 Sequence Map
    [Orciny Device Sequence 0.csv, Orciny Device Sequence 1.csv, Orciny Device Sequence 2.csv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]
2026-04-19 Add Adafruit_NeoPixel and Adafruit_PWM_Servo_Driver_Library; update rp2040_fx_starter.ino with print output for sequence phases and palette helpers
    [Orciny Device Sequencing.csv]
2026-04-20 v0.3.5: Most current functioning version with robust state and button logic
2026-04-20 docs: update README and TROUBLESHOOTING to v0.2.8, reflect current setup and workflow
2026-04-20 docs: mark v0.3.7 as most current functioning version in README
2026-04-21 v0.6.0: Documentation, comments, and version updates; clarify PWM pin usage and animation logic
2026-04-21 docs: Add explicit pump/filament sequence timing to animation timeline
2026-04-21 Update Orciny Device Animation Timeline
    Cleaned up duplicated info
2026-04-21 0.7.0 Release, updated documentation, updated code.
    [Orciny Device Sequencing.xlsx]
